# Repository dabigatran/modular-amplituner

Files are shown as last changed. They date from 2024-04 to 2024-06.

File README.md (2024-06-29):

# Modular Amplituner

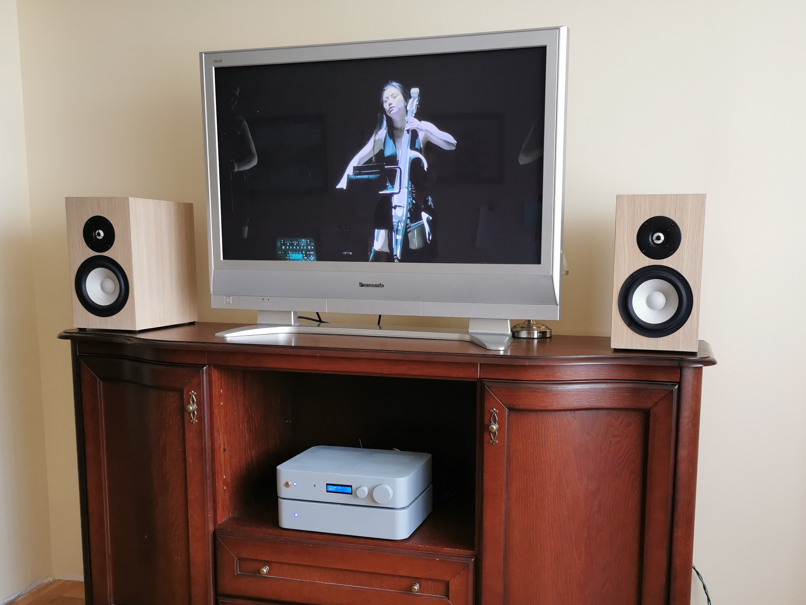
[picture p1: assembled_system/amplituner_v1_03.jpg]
Project Logo


## Overview

**Project Short Title:** Audio Path Control Using I2C and SPI Protocols</br>
**Project Full Title:** Audio path (I2S and analog bus) control using I2C and SPI protocols on the example of a modular audio-video system consisting of a receiver (tuner), an amplifier and a speaker system

**Abstract:** This project aims to create a modular audio/video system consisting of an audio/video receiver, audio amplifier, and stereo speaker system using commercially available components. The system uses universal I2C and SPI protocols for control and the I2S and analog bus for audio data transmission. Its modular design allows for both hardware and software upgrades, catering to advanced users and audio hobbyists.

**Introduction:**  The market for consumer devices for managing audio and video transmission is dominated by commercial solutions with a top-down imposed way of controlling and processing audio-visual data and no possibility of interference from the advanced user in the hardware part of the device as well as the software part. In addition, these systems are characterized by a lack of modularity, which consequently leaves the user without the possibility of a PC-like hardware upgrade. The goal of this project is to create a modular audio/video system consisting of an audio/video receiver, audio amplifier and stereo speaker system with software for home use, based on commercially available components. The system is planned to use universal I2C and SPI protocols to control individual modules and audio path (the I2S and analog bus). One of the system's most distinctive features is its modularity. This refers to the ability to make changes to the system, both in its individual components and in the software, according to the individual audio needs of the advanced user (audio hobbyist) over the course of the system's use.

## Features

### Speaker System
- **Sound Intensity:** 105dB (Max SPL)
- **Sensitivity:** 84dB
- **Frequency Range:** 45 – 24000 Hz
- **Impedance Range:** 4-8 Ohms

### Audio Amplifier
- **Power Rating:** Up to 150W
- **Type:** Class D stereo amplifier
- **Inputs:** 2x RCA audio inputs
- **Outputs:** 2x speaker outputs

### Audio Receiver
- **Digital Audio Sources:** Spdif, Bluetooth, USBC
- **Analog Audio Sources:** 2x RCA
- **Audio-Video Sources:** 4x HDMI
- **Outputs:** HDMI, 2x RCA
- **Control:** Volume, sound source, bass, treble, balance
- **Display:** LCD for current status and volume
- **Remote Control:** Infrared with Chromecast integration

## Assembled System - [presentations and photos](assembled_system/readme.md)

## System Architecture

### Schematics

#### Receiver - [technical specification](receiver/readme.md)
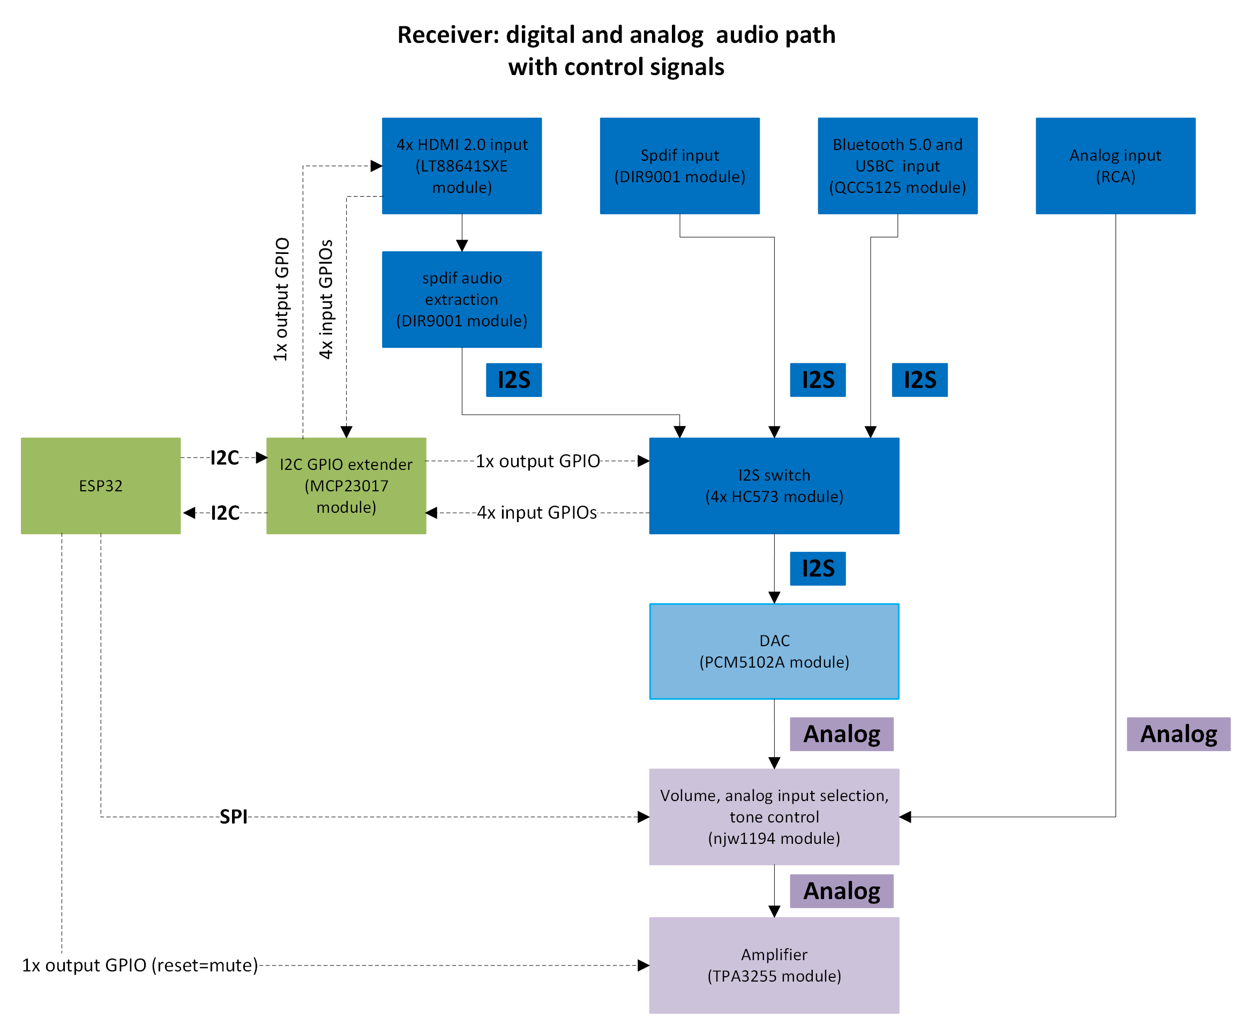
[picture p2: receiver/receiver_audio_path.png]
Receiver Audio Path Schematic


#### Amplifier - [technical specification](amplifier/readme.md)
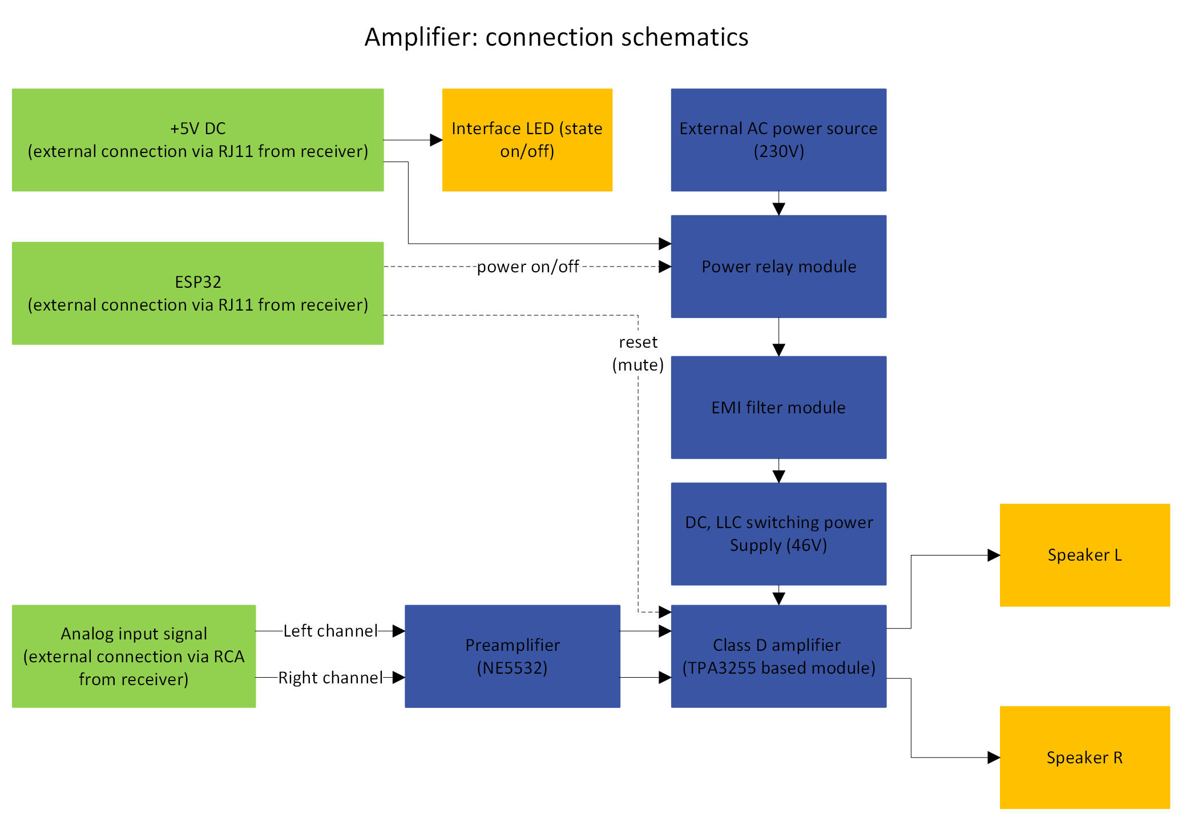
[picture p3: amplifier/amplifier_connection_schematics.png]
Amplifier Schematic


#### Speakers - [technical specification](speakers/readme.md) - based on Open Source [Bromo Project](https://sbacoustics.com/product/bromo/)
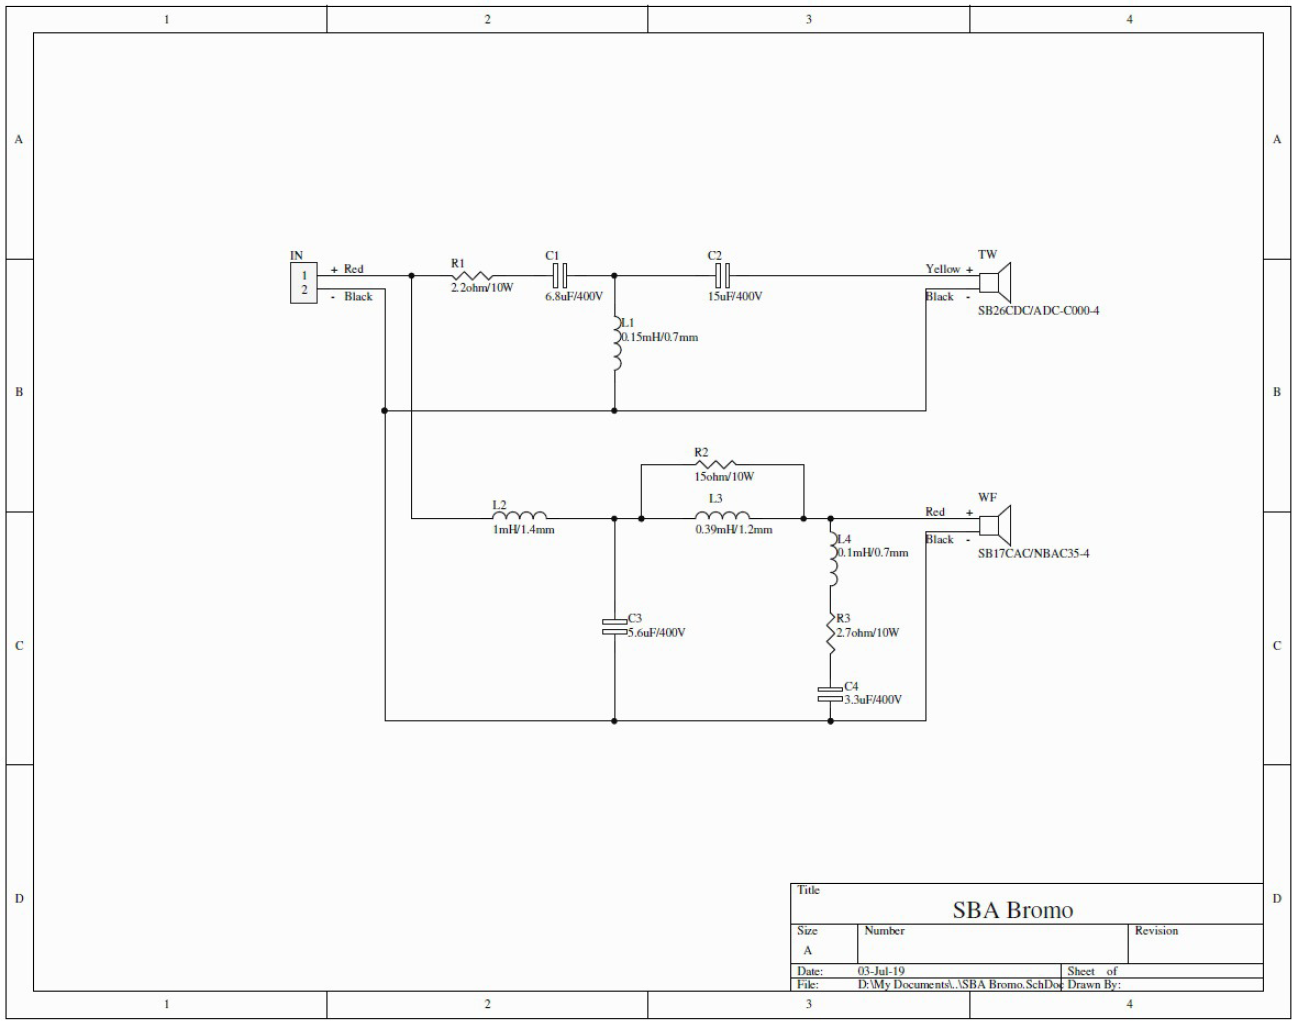
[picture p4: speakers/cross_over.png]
Speaker Cross-over Schematic

   
#### Firmware - [description and code](main/readme.md)
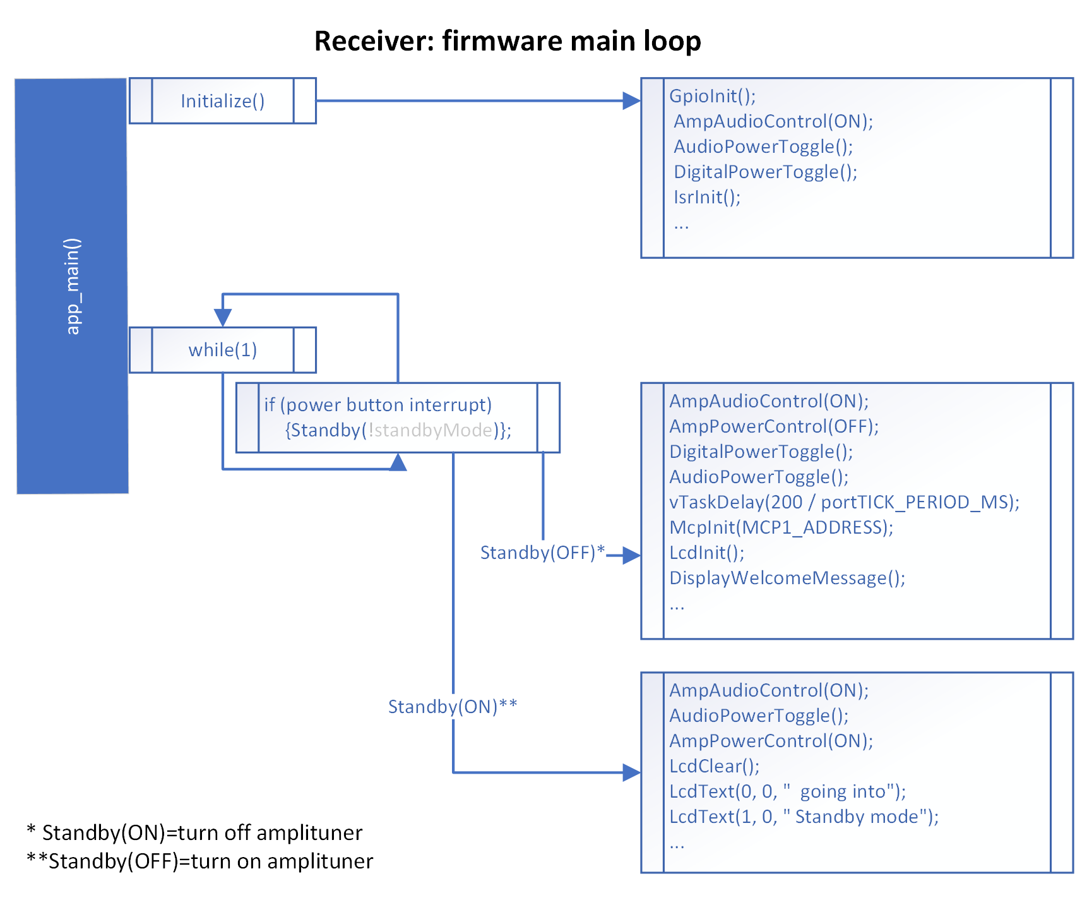
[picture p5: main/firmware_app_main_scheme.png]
Firmaware Main loop Schematic


## Installation

1. Clone the repository:
   ```bash
   git clone https://github.com/dabigatran/modular-amplituner.git

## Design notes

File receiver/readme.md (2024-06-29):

# Receiver Schematics

Receiver Audio Path Schematic

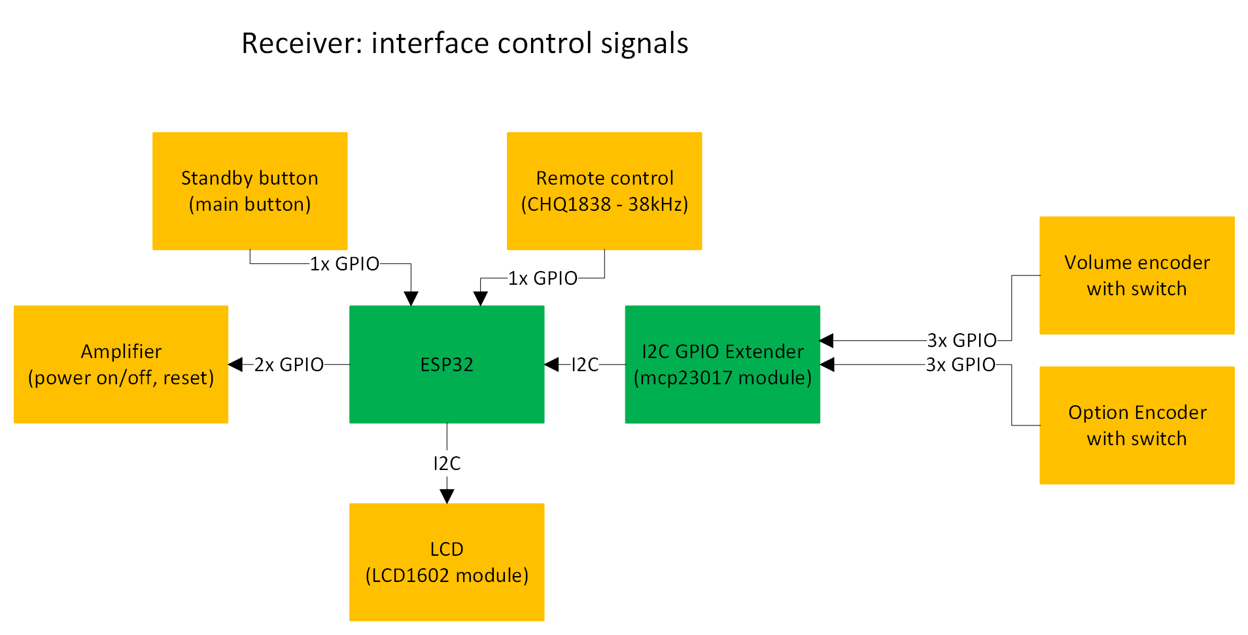
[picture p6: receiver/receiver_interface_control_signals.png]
Receiver User Interface Schematic


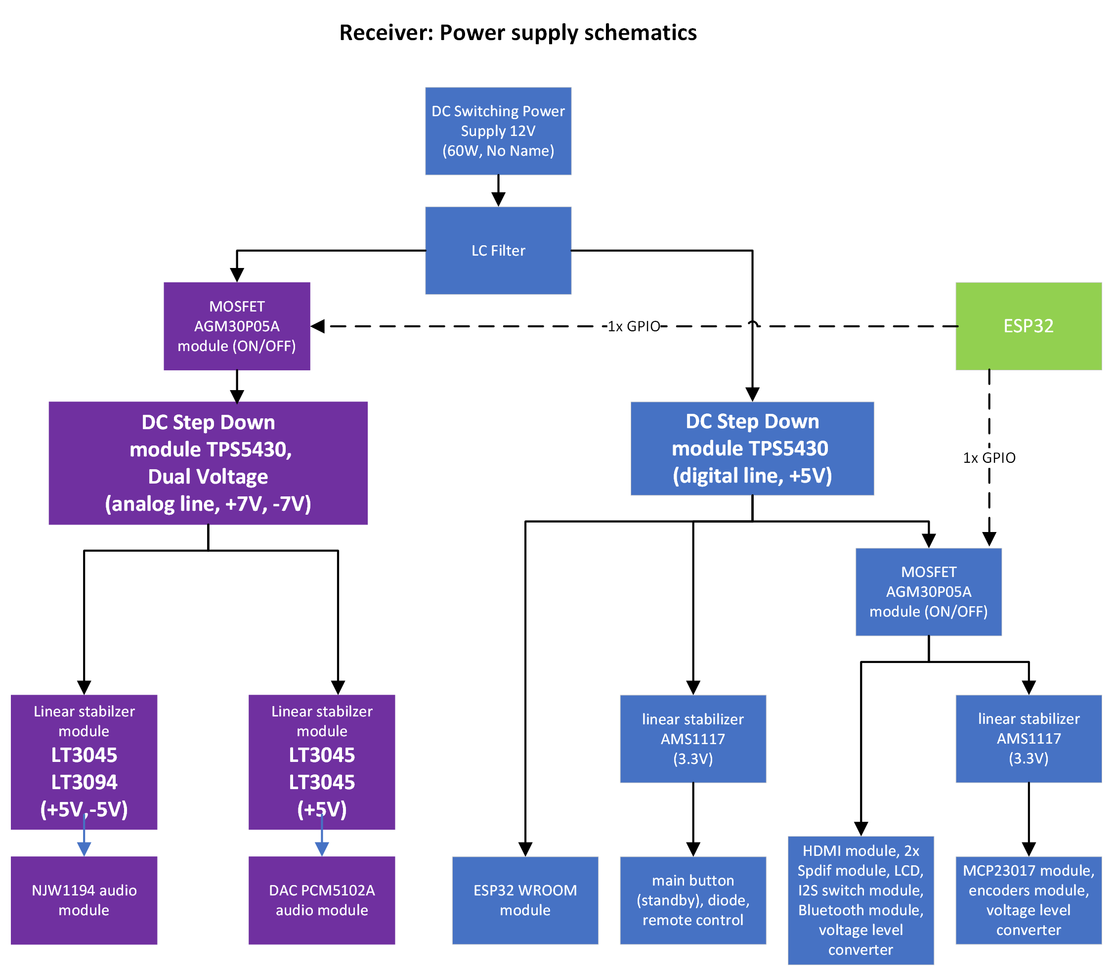
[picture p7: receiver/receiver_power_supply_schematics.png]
Receiver Power Supply Schematic


# Assembled Receiver

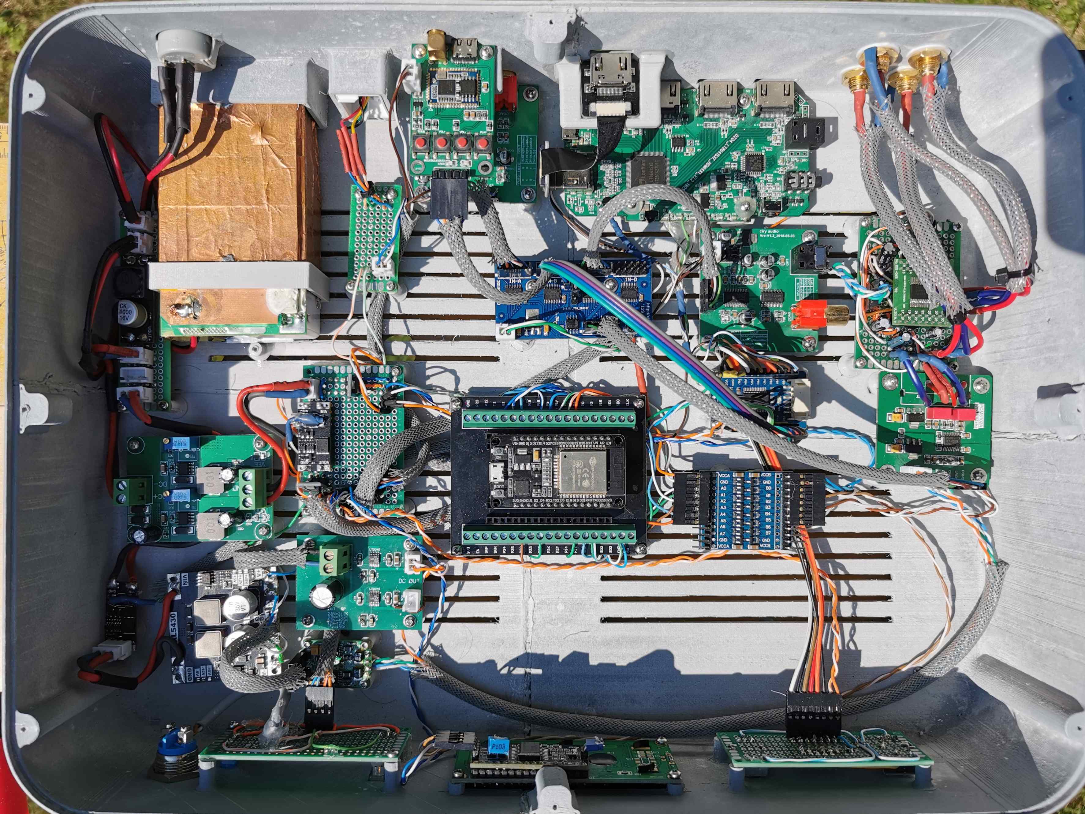
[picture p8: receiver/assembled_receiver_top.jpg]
Assembled Receiver Top


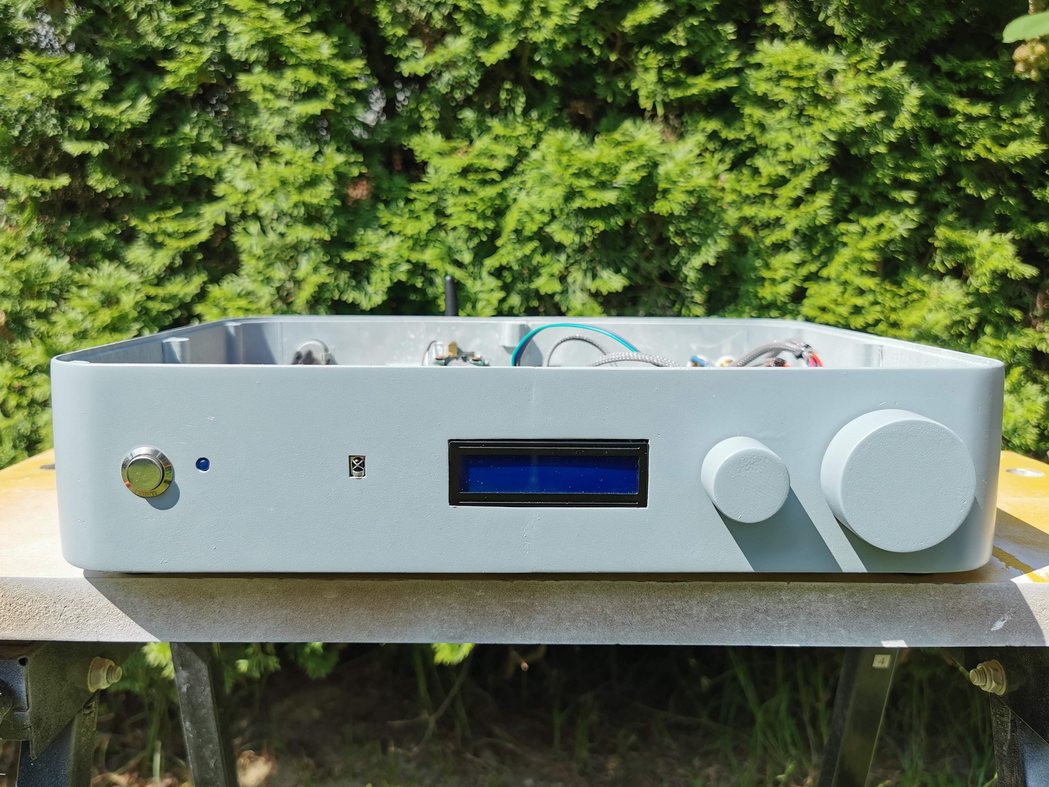
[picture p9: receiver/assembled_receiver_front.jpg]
Assemebled Receiver Front


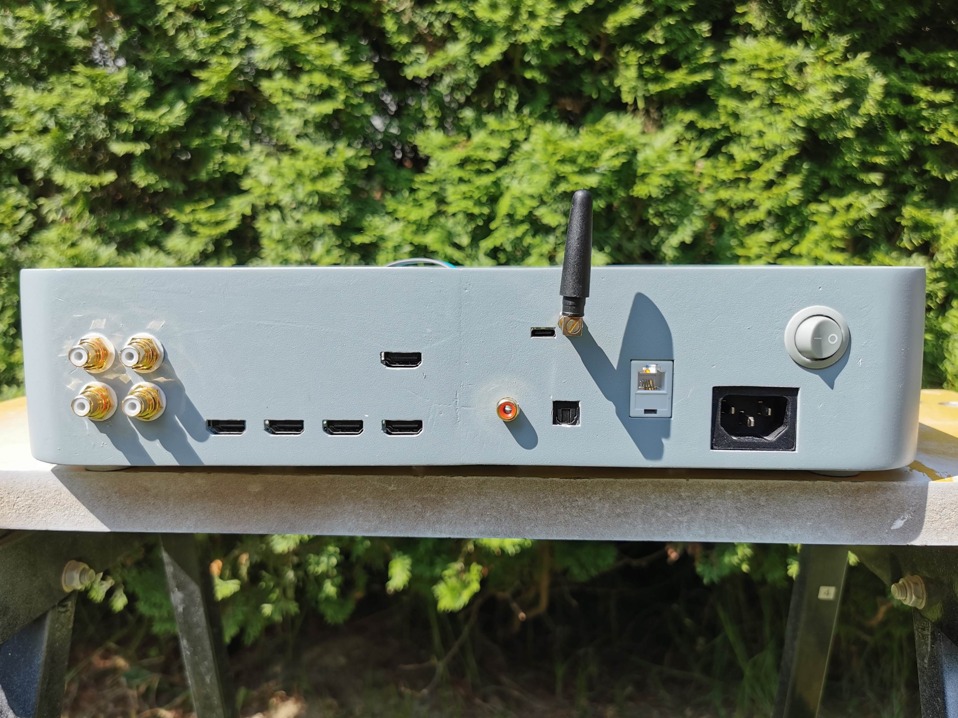
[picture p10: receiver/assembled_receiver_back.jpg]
Assemebled Receiver Back


# Receiver Components

### Power Supply
- **Switching Power Supply (60W, 12V)**
  - No-Name, taken from notebook
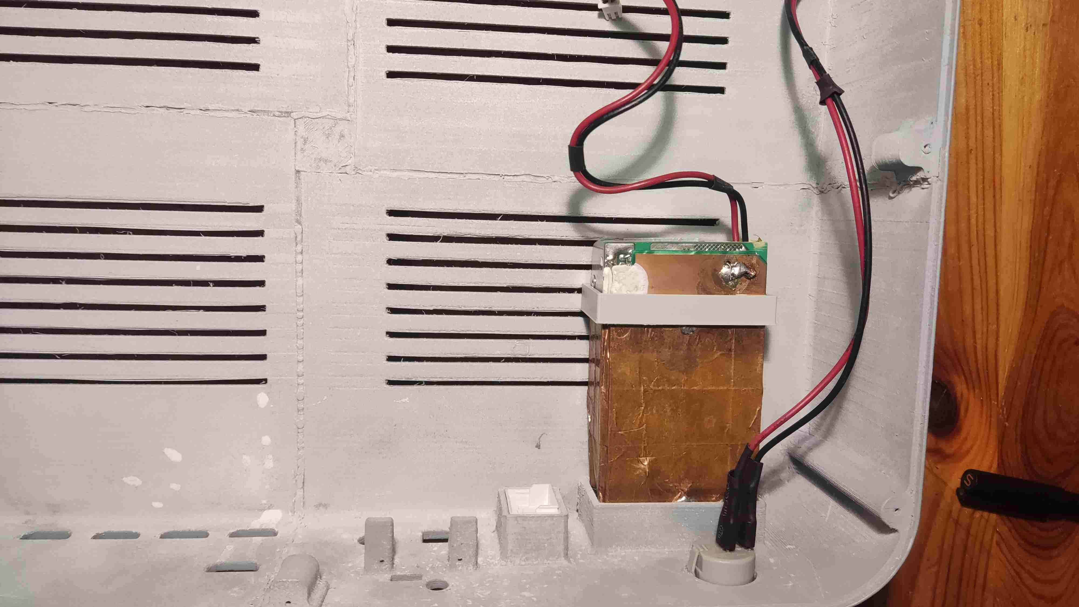
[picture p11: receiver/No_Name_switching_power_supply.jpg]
  - 

### Converters & Stabilizers
- **Step-Down Converter Modules (2x)**
  - No-Name, based on TPS5430 chip (Texas Instruments)
  - [Datasheet](../receiver/tps5430.pdf)
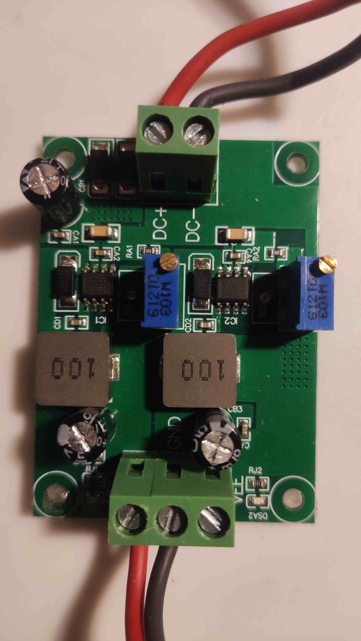
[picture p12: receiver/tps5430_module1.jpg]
  - 
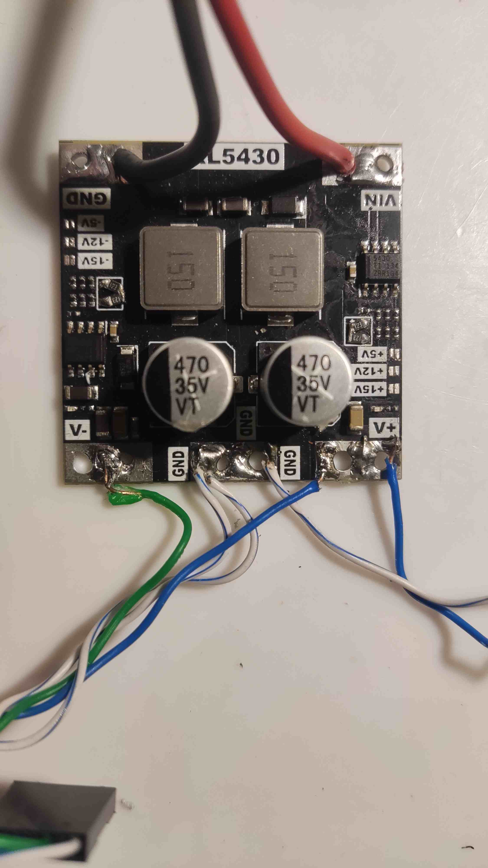
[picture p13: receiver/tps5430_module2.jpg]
  - 
- **Low-Noise Linear Stabilizer Module (+5V, 500mA)**
  - No-Name, based on 2x LT3045 chip (Analog Devices)
  - [Datasheet](../receiver/lt3045.pdf)
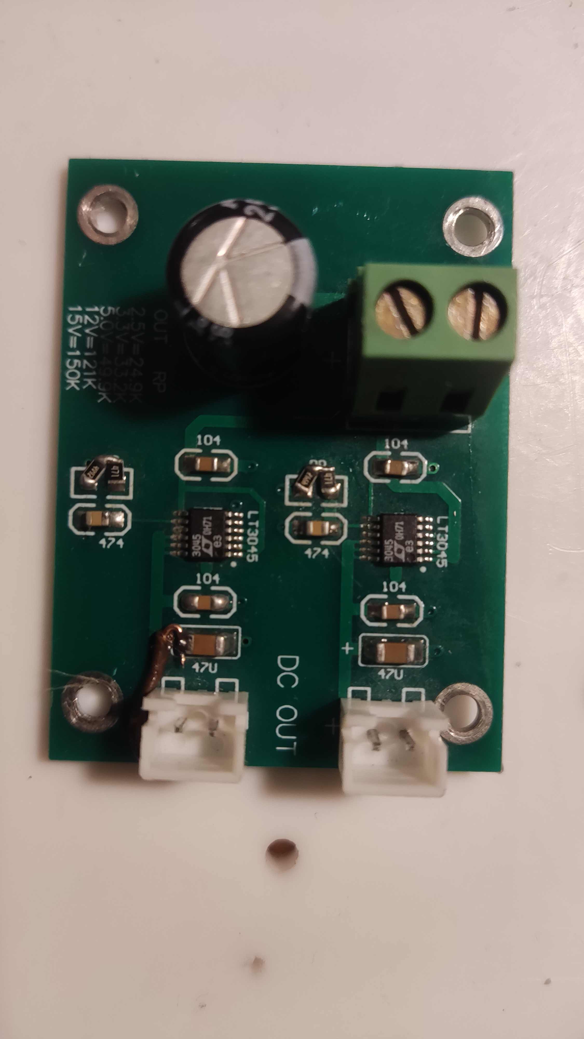
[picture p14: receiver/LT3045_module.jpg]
  - 
- **Low-Noise Linear Stabilizer Module (+5V and -5V, 300mA)**
  - FUTECH, based on LT3045 and LT3094 chips (Analog Devices)
  - [Datasheet](../receiver/LT3094.pdf)
  - [Datasheet](../receiver/lt3045.pdf)
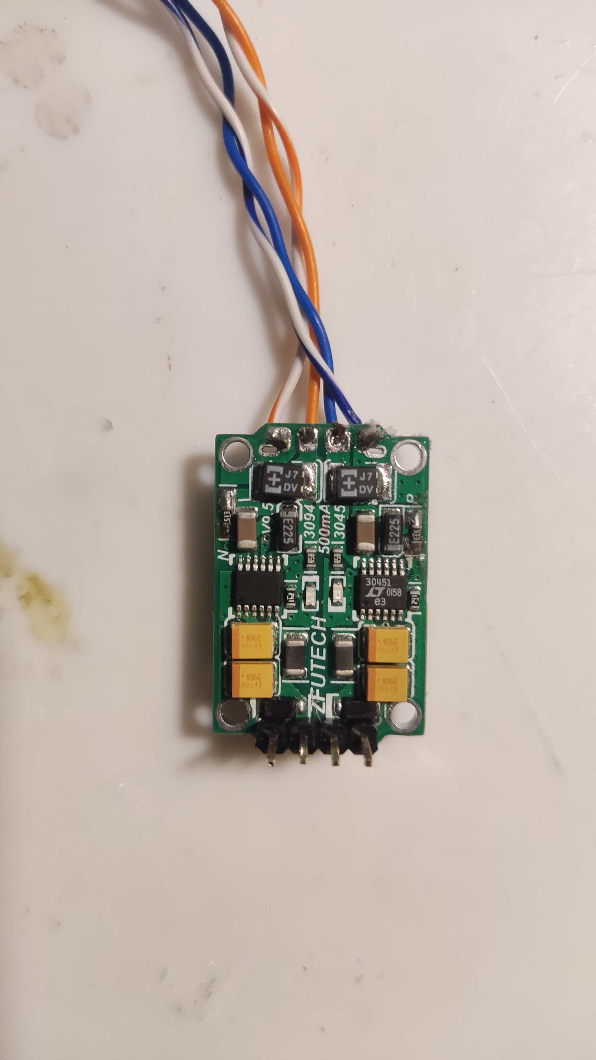
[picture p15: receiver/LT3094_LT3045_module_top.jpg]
  - 
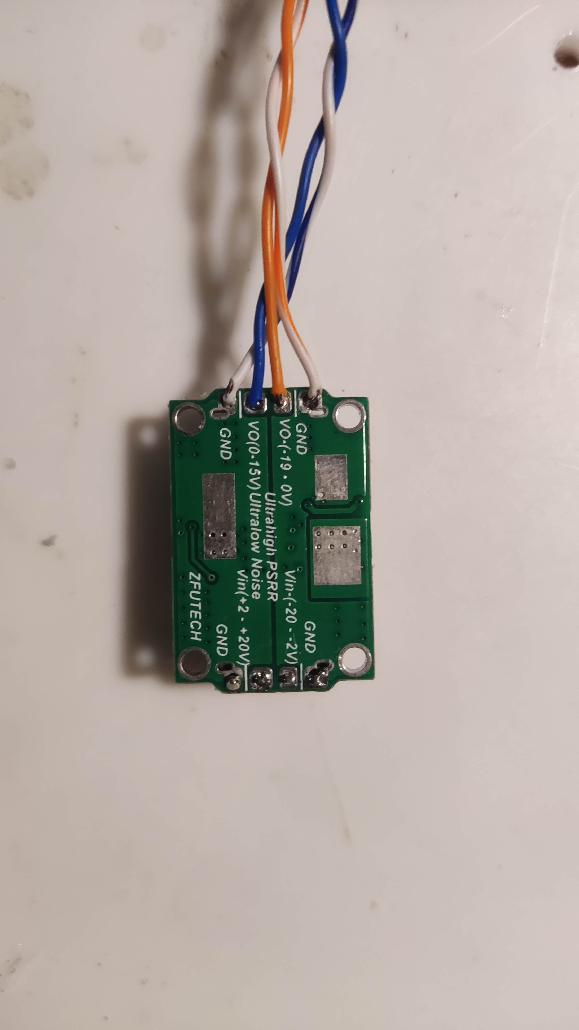
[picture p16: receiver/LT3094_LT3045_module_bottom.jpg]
  - 

### Microcontroller & Extenders
- **Microcontroller Module**
  - ESP32 WROOM-32 DEV KIT – Dual Core Tensilica LX6 240 MHz (Espressif Systems)
  - [Datasheet](../receiver/ESP-WROOM-32_datasheet.pdf)
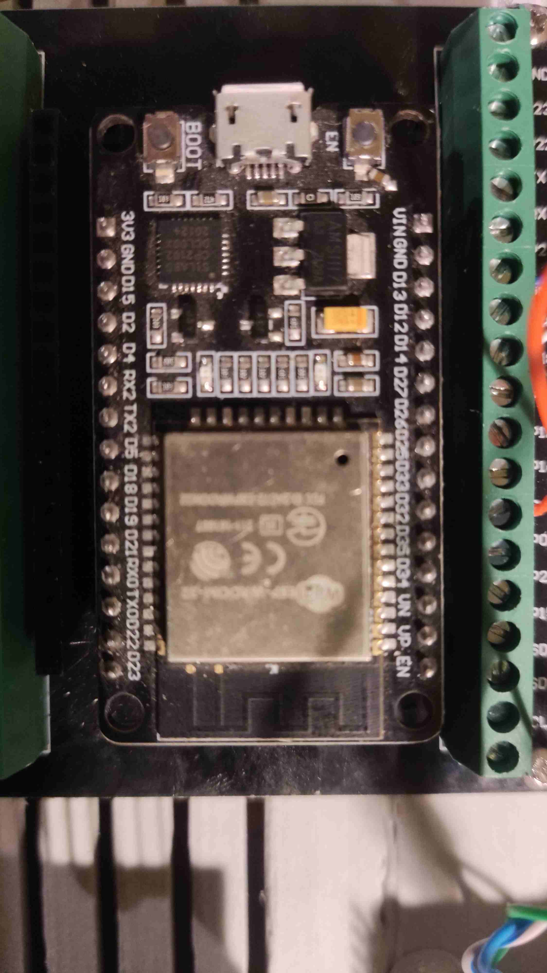
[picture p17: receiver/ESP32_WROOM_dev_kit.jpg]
  - 
- **I2C Bus Extender Module**
  - MCP23017 (Waveshare 15391)
  - [Datasheet](../receiver/MCP23017.pdf)
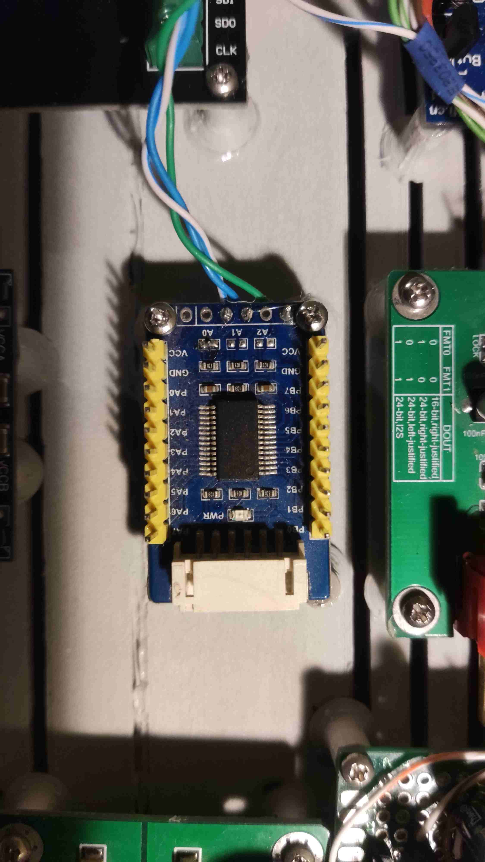
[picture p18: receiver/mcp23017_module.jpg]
  - 

### Displays & Controllers
- **LCD Display Module**
  - LCD1602 (No-Name)
  - [Datasheet](../receiver/LCD1602.pdf)
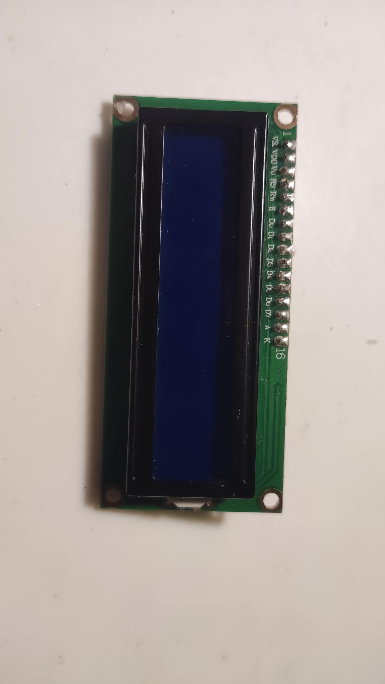
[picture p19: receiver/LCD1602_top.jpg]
  - 
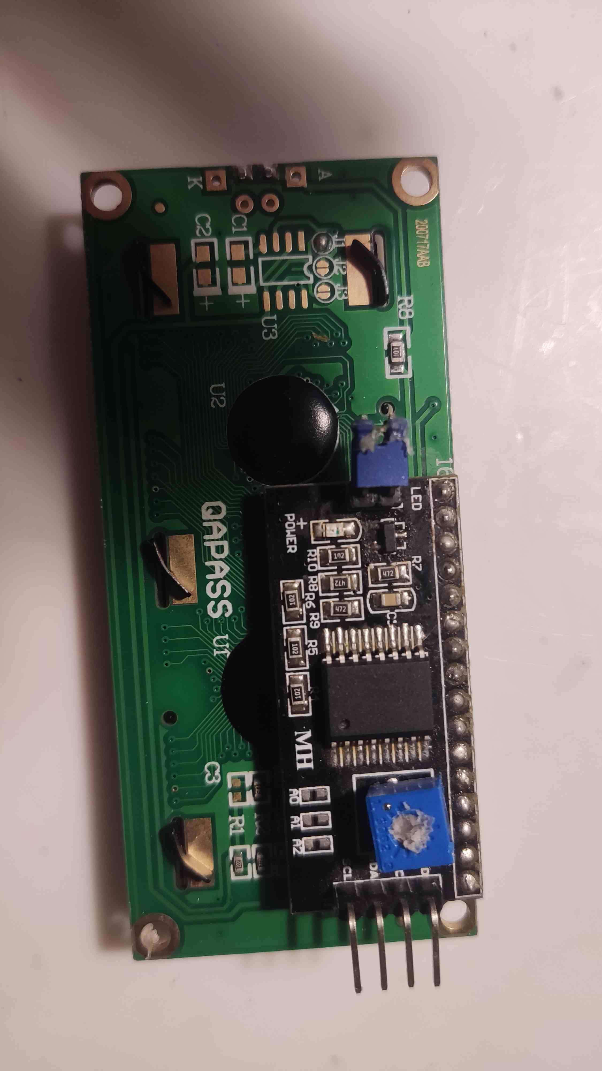
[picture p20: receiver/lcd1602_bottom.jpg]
  - 
- **LCD Controller Module (via I2C)**
  - Based on PCF8574 (Philips Semiconductors)
  - [Datasheet](../receiver/pcf8574.pdf)

### Audio Components
- **DAC Module**
  - Based on PCM5102 chip (Burr-Brown)
  - [Datasheet](../receiver/pcm5102a.pdf)
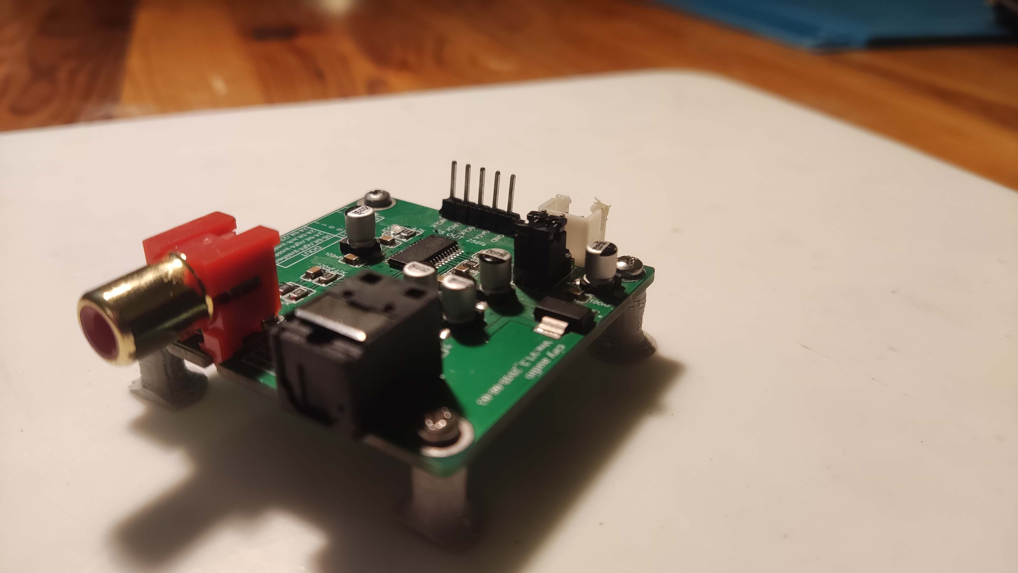
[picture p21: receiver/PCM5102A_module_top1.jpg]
  - 
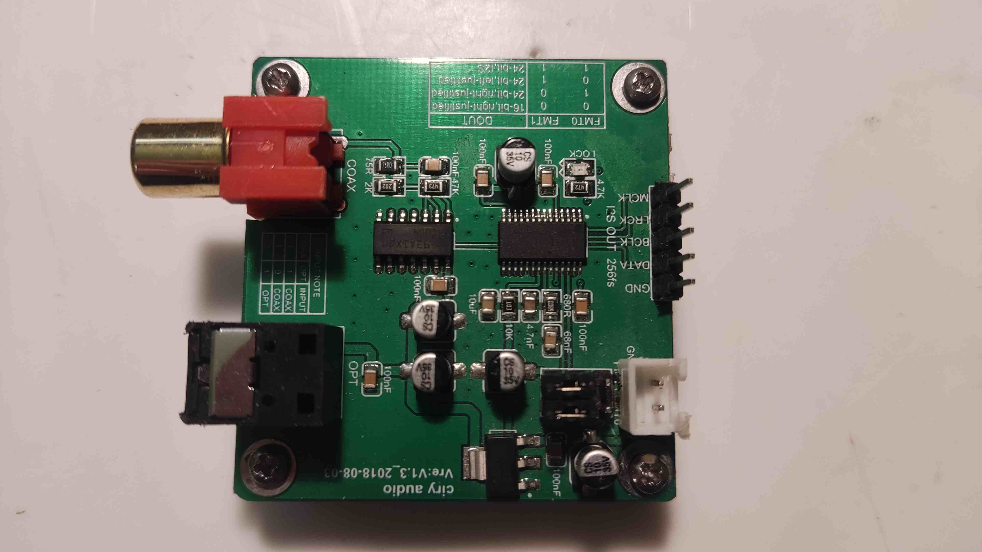
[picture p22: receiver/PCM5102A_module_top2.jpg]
  - 
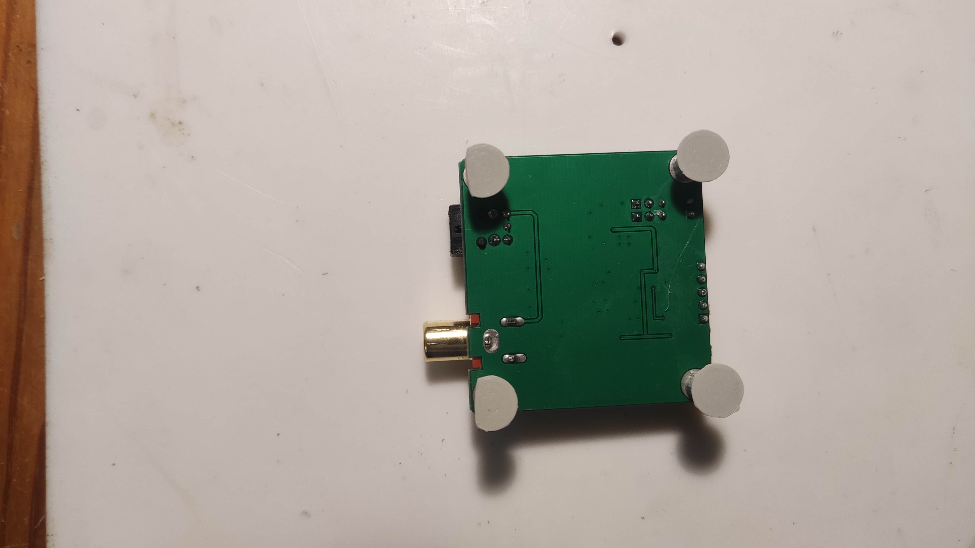
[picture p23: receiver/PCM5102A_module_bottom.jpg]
  - 
- **Analog Audio Control Module**
  - Based on NJW1194 chip (New Japan Radio)
  - [Datasheet](../receiver/NJW1194.PDF)
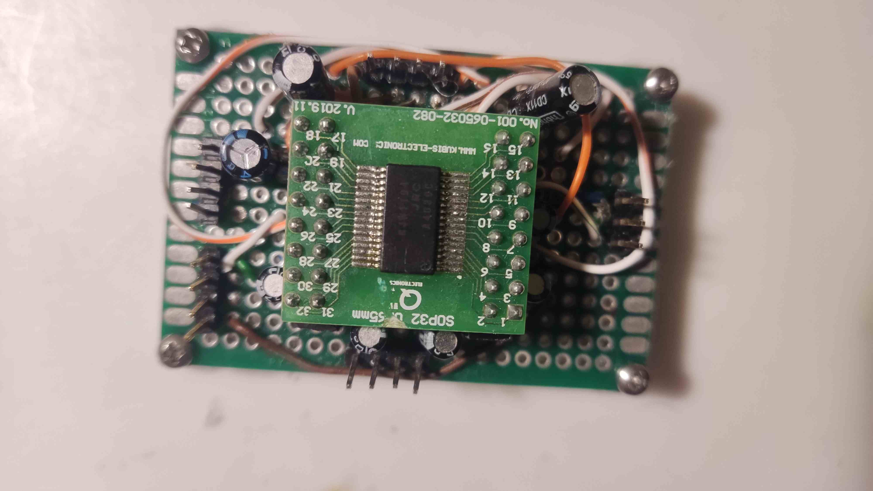
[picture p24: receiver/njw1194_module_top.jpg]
  - 
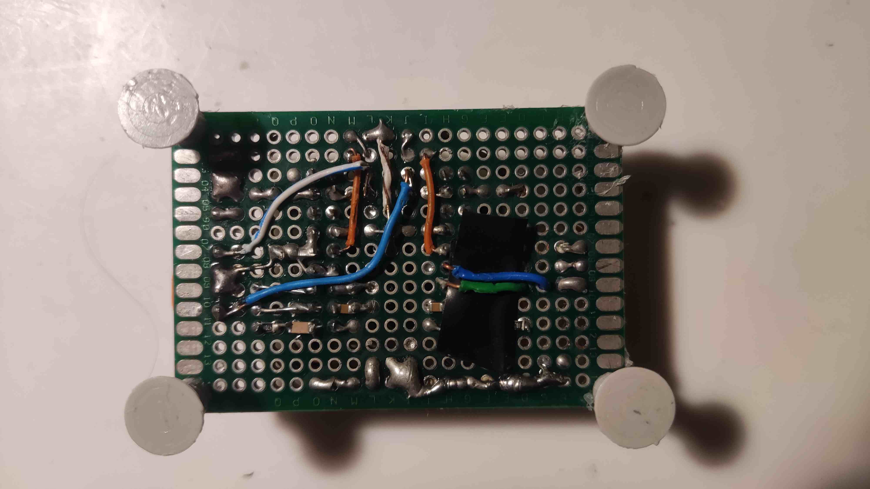
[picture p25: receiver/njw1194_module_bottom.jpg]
  - 
- **Bluetooth 5.0 Stereo Module**
  - Based on QCC5125 chip (Qualcomm)
  - [Datasheet](../receiver/SJR-BTM525_SPEC.pdf)
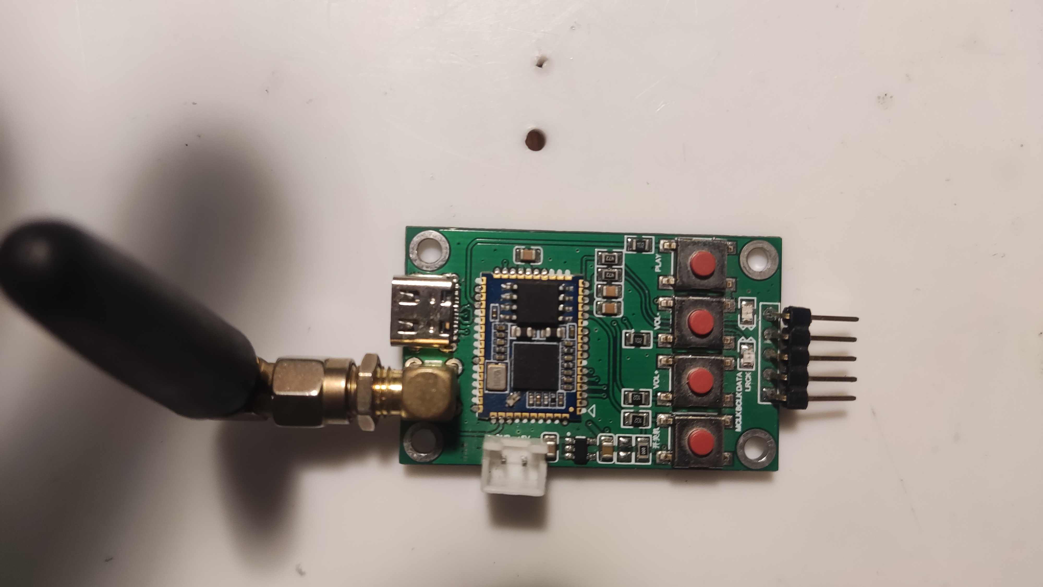
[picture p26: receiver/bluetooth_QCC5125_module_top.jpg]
  - 
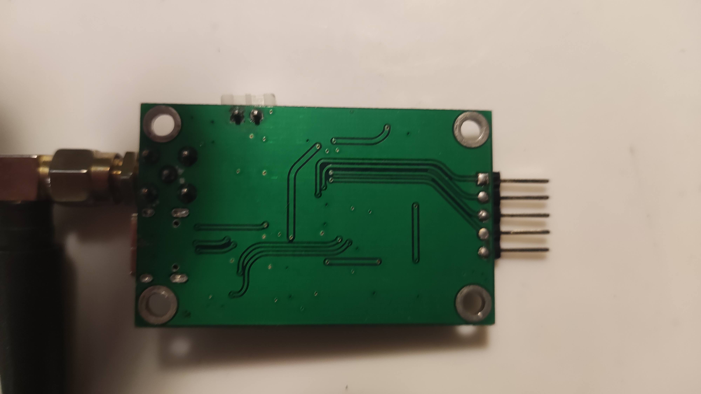
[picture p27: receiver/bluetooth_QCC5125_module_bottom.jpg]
  - 
- **Digital Signal Converter (SPDIF to I2S)**
  - Based on DIR9001 chip (Texas Instruments)
  - [Datasheet](../receiver/dir9001.pdf)
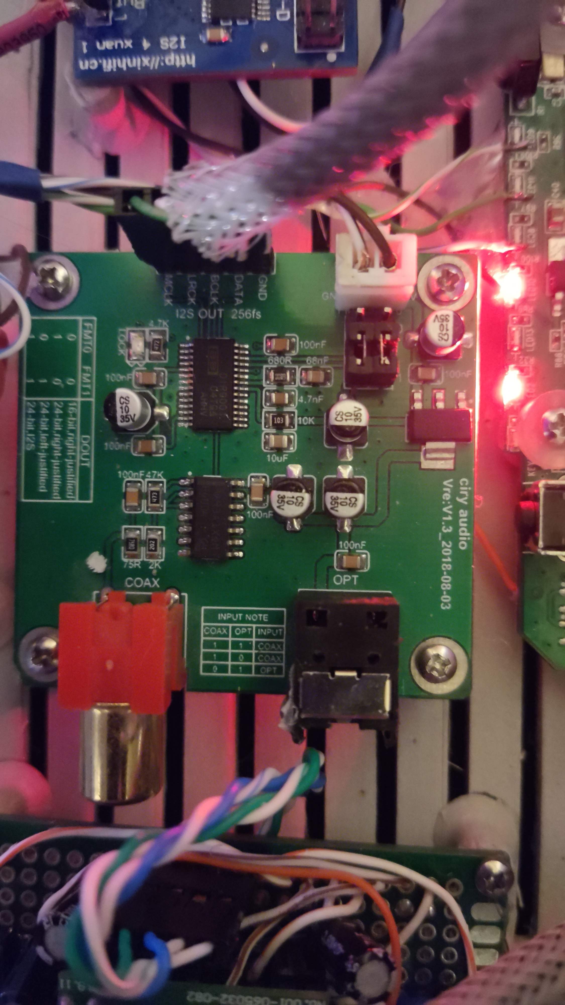
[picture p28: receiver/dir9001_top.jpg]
  - 
- **I2S Signal Switch Module**
  - Based on HC273 chip (Texas Instruments)
  - [Datasheet](../receiver/cd54hc573.pdf)
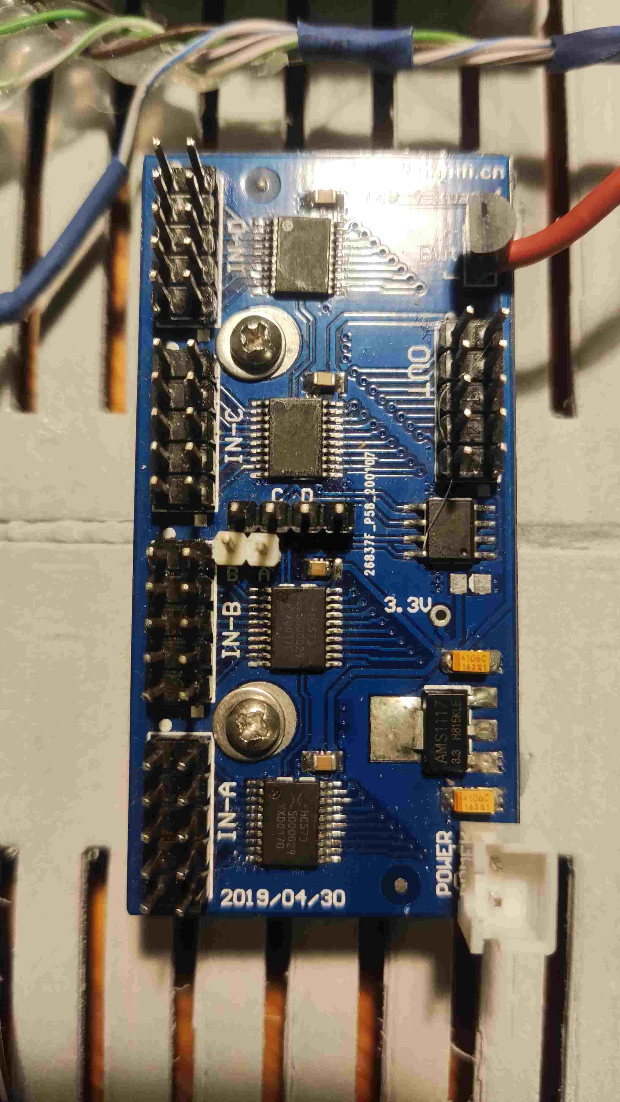
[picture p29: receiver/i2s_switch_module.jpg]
  - 
  - 

### HDMI & Logic Converters
- **HDMI Source and Output Control Module**
  - No-Name, based on LT8641SXE chip (Lontium Semiconductors)
  - [Datasheet](../receiver/LT8641SXE_Product_Brief.pdf)
  - 
  - 
  - 
  - 
- **5V-3.3V Logic Level Converter Module**
  - No-Name
  - 

### Controls & Interfaces
- **Control Module with Encoders**
  - Two PEC11H series encoders and switch (Bourns)
  - [Datasheet](../receiver/pec11h-1879218.pdf)
  - 
  - 
- **Inverter Module with Schmitt Circuit**
  - Based on 74HC14 integrated circuit (Diodes Incorporated)
  - [Datasheet](../receiver/74HC14.pdf)

### Miscellaneous
- **Other Components**
  - NPN transistors, resistors, capacitors, universal PCBs, wiring, RCA connectors, USB, Bluetooth antennas, heat sink
- **Enclosure**
  - See [Enclosure](../enclosure/readme.md)

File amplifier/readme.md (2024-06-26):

# Amplifier Schematics

Amplifier Schematic
Assembled amplifier photo
Assembled amplifier photo
Assembled amplifier photo
Assembled amplifier photo
Assembled amplifier photo

# Amplifier Components

## Power Supply
- **Dual LLC 500W, 46V Switching Power Supply Module**
  - Lusya C1-009
  - LLC Power Supply photo
  - LLC Power Supply photo
  - LLC Power Supply photo

## Amplifier Modules
- **260W Class D Stereo Amplifier Module**
  - 3eaudio model EAUMT-0260-2-B, based on TPA3255 IC (Texas Instruments)
  - THD+N < 0.01% in the range of 0.3W - 200W at 4Ω, 111dBA dynamic range
  - [3eaudio Product Page](https://www.3e-audio.com/amplifier-kits/tpa3255-2ch-260w/)
  - [Product Datasheet](../amplifier/DS_EAUMT-0260-2-A_Rev1.0.pdf)
  - [tpa3255 Datasheet](../amplifier/tpa3255B.pdf)
  - DC Voltage supplied - 46V (compromise between Power, THD+N, Heat, speakers resistance)
  - output power rating - 150W (page 11, Figure 8, [tpa3255 Datasheet](../amplifier/tpa3255B.pdf)) .
  - Class D Amplifier photo
  - Class D Amplifier photo

## EMI & Safety
- **EMI Filter Module**
  - No-Name
  - EMI Filter Photo
  - EMI Filter Photo
- **Power Relay**
  - No-Name
  - Power Relay Photo
  - Power Relay Photo

## Enclosure
- **Enclosure**
  - See [Enclosure](../enclosure/readme.md)

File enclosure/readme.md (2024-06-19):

# Enclosure

## STLs
- [Amplifier Base](../enclosure/amplifier_base.stl)
- [Receiver Base](../enclosure/receiver_base.stl)
- [Receiver and Amplifier Cover](../enclosure/receiver_and_amplifier_cover.stl)
- [Receiver and Amplifier Cover Support](../enclosure/receiver_and_amplifier_cover_support.stl)
- [Receiver and Amplifier PCB Support](../enclosure/receiver_and_amplifier_pcb_support.stl)
- [Receiver and Amplifier Pad](../enclosure/receiver_and_amplifier_pad.stl)
- [Receiver Power Supply Support](../enclosure/receiver_power_supply_support.stl)
- [Volume Knob](../enclosure/volume_knob.stl)
- [Option Knob](../enclosure/option_knob.stl)

## Printing Details
- **Material**: Impact PLA (Fiberology)
- **Print Temperature**: 225°C
- **Print Bed Temperature**: 50°C for the first layer, 35°C for subsequent layers
- **Adhesive**: Dimafix
- **Print Layer Height**: 0.2 mm
- **Supports**: Yes (use according to your printer's requirements)

## Comments
- **Adhesives**: PCB supports and power supply pads were glued to the case with CA300 and activator.
- **Mounting**: PCBs, covers, and pads were screwed to the case.
- **Print Bed Constraints**: Due to the small print bed of my printer (220x220mm), I had to divide covers and the base of the amplifier and receiver into 4 parts. Printing took 120 hours for all components, and I used approximately 2kg of Impact PLA.
- **Printing Orientation**: Printed with the front face and back face of the receiver/amplifier on the printer's bed to hide print layers.
- **Post-Processing**: To hide layering, I additionally sanded the cases and used primer, car filler, and spray paint.

## Photos
Printer
Receiver Enclosure Front
Receiver Enclosure Front
Receiver Enclosure Front
Spray Glue Filler Primer

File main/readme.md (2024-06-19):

# Firmware
- app_main() Schematics

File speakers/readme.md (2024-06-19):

# Speakers 
- based on SBAcoustics Open Source [Bromo Project](https://sbacoustics.com/product/bromo/)

# Speaker Components

## Tweeters
- **2x SB26CDC-C000-4 Tweeter**
  - [Datasheet](../speakers/SB26CDC-C000-4.pdf)

## Mid-Bass Speakers
- **2x SB17CAC35-4 Mid-Bass Speaker**
  - [Datasheet](../speakers/6in-SB17CAC35-4.pdf)

## Crossovers
- **Set of Components for Two Crossovers (Jantzen Audio)**
  - [Crossover Schematic](../speakers/Bromo-Crossover-Schematic.pdf)

## Enclosure
- **18 mm Thick MDF Board**
  - [Cabinet Drawing](../speakers/Bromo-Cabinet-Drawing.pdf)

## Additional Components
- **Set of Connectors**
- **Bass-Reflex Tunnels**
- **Veneer and Veneer Glue**
- **Varnish**

## Photos
  
  
  
  
  
  
  
  
  



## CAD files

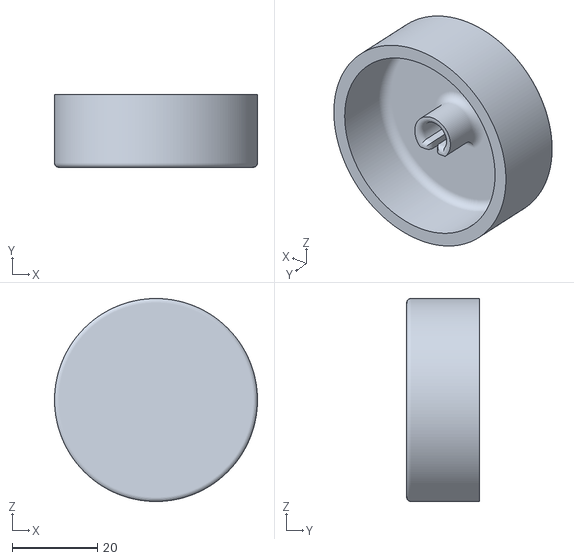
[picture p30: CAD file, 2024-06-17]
enclosure/volume_knob.stl
47.5 x 17.0 x 47.5

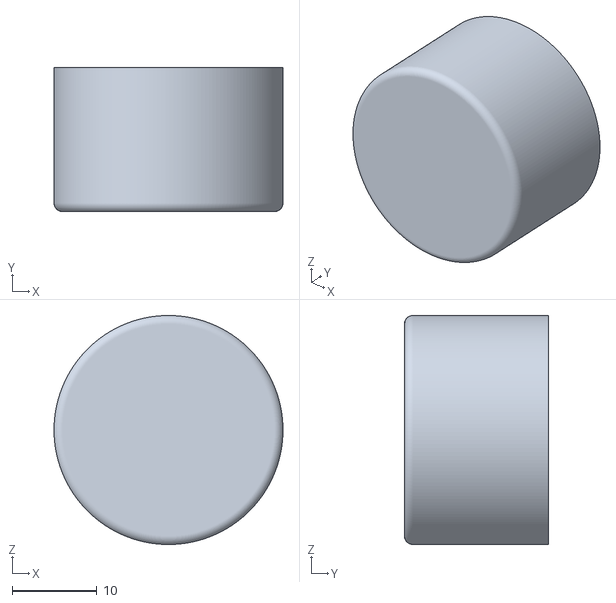
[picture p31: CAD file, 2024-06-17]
enclosure/option_knob.stl
27.0 x 17.0 x 27.0

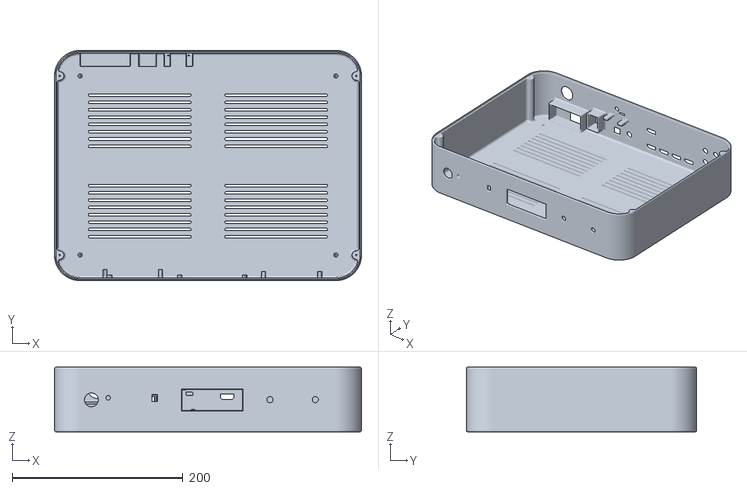
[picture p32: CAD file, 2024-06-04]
enclosure/receiver_base.stl
360.0 x 270.0 x 76.0

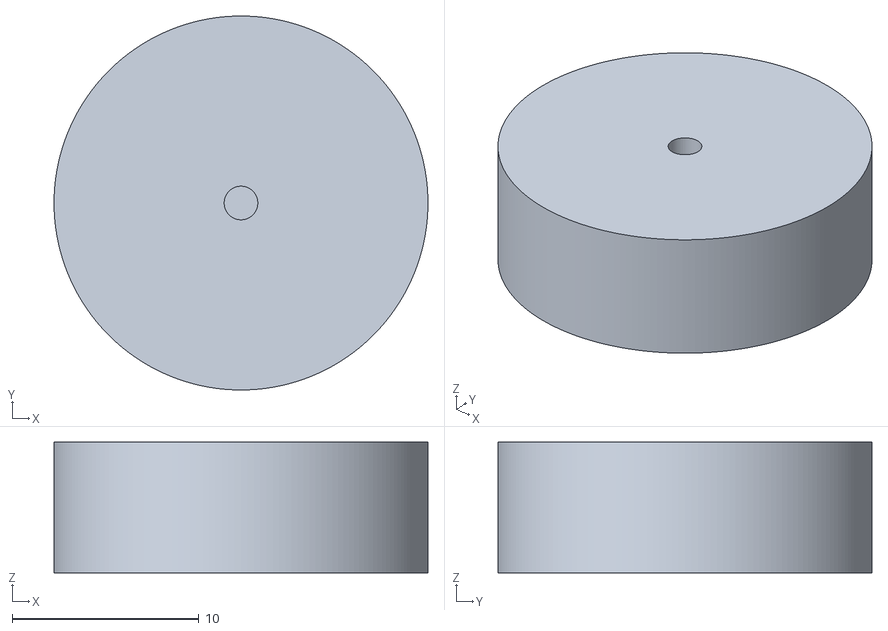
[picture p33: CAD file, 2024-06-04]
enclosure/receiver_and_amplifier_pad.stl
20.0 x 20.0 x 7.00

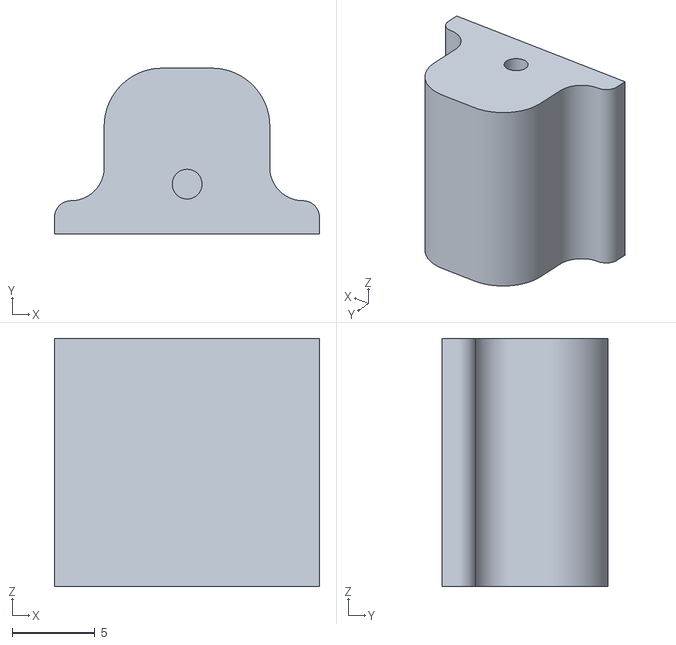
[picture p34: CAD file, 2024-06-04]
enclosure/receiver_and_amplifier_cover_support.stl
16.0 x 10.0 x 15.0

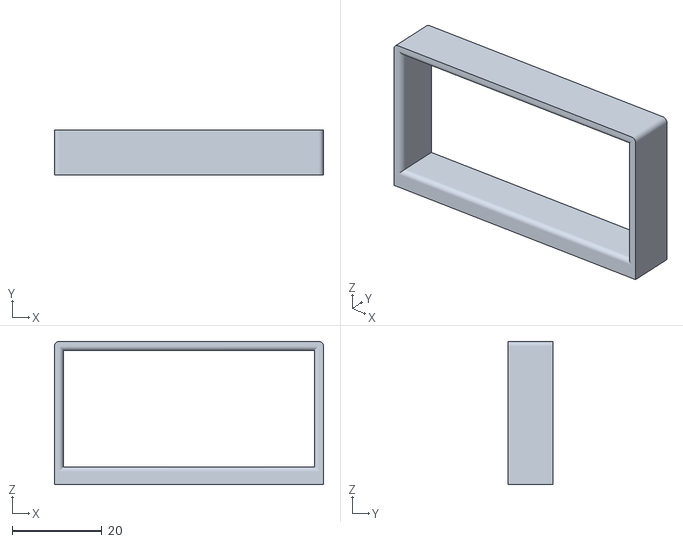
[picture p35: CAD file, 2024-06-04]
enclosure/receiver_power_supply_support.stl
60.0 x 10.0 x 31.9

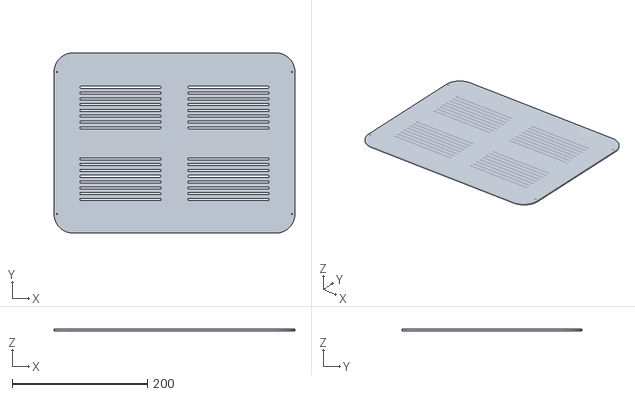
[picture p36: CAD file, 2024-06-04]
enclosure/receiver_and_amplifier_cover.stl
356.6 x 266.6 x 3.00

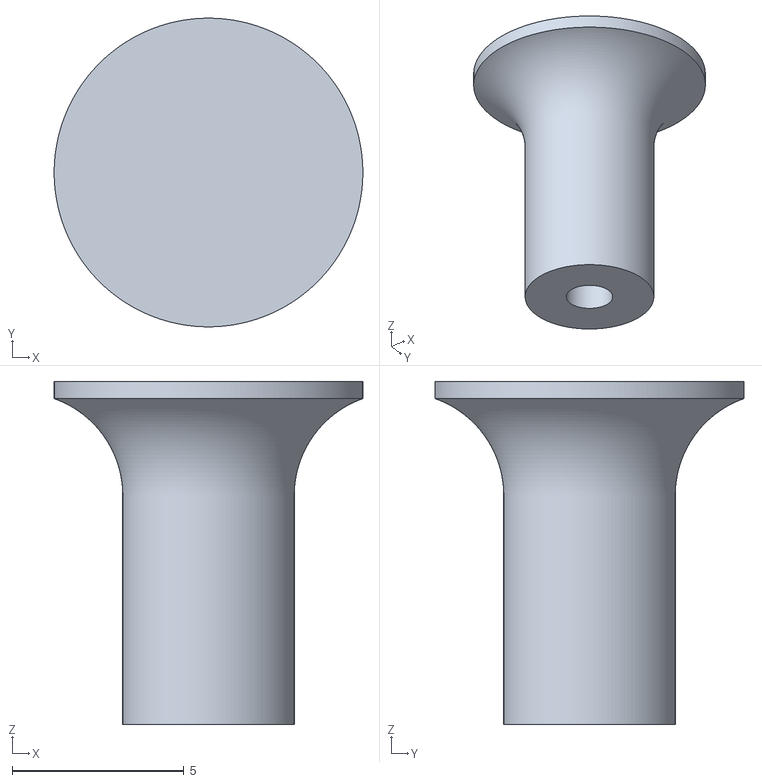
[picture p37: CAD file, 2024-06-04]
enclosure/receiver_and_amplifier_pcb_support.stl
9.00 x 9.00 x 10.0

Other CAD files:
enclosure/amplifier_base.stl

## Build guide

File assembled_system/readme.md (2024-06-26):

# Assembled and working system (receiver, amplifier, speakers)
## Presentations
[Amplituner User Interface (download .mp4 to view)](https://raw.githubusercontent.com/dabigatran/modular-amplituner/main/assembled_system/amplituner_v1_main.mp4)

[Amplituner Chromecast Remote Control (download .mp4 to view)](https://raw.githubusercontent.com/dabigatran/modular-amplituner/main/assembled_system/amplituner_v1_remote.mp4)

## Photos
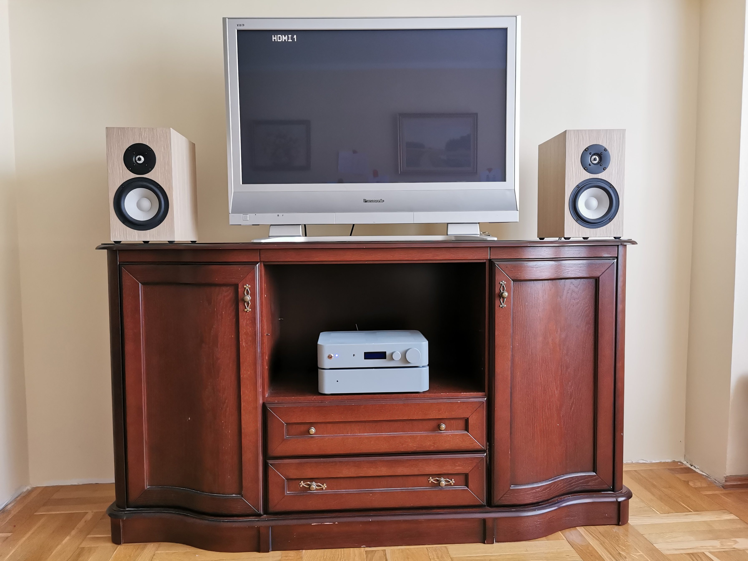
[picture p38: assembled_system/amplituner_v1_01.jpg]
amplituner_1

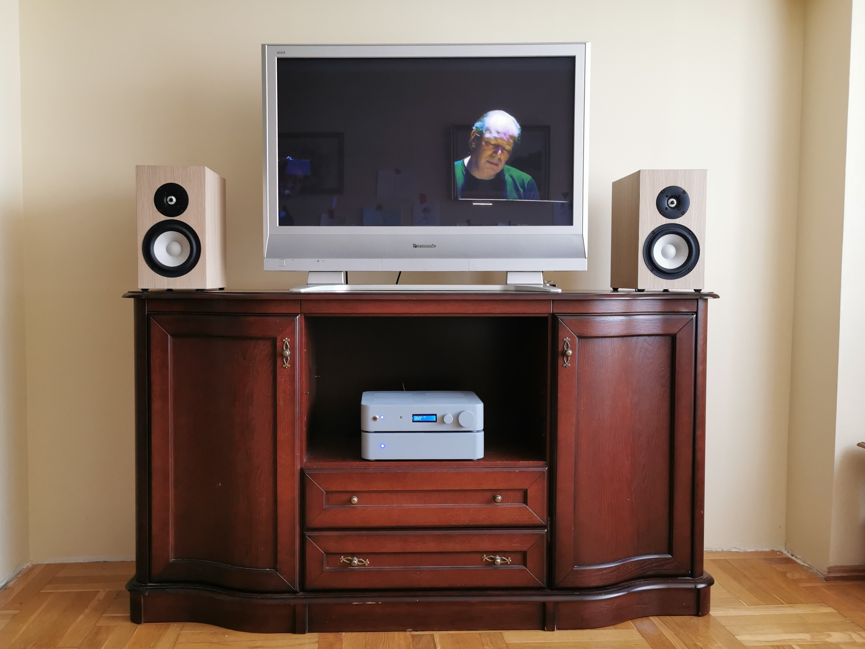
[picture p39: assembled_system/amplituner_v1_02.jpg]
amplituner_2

amplituner_3
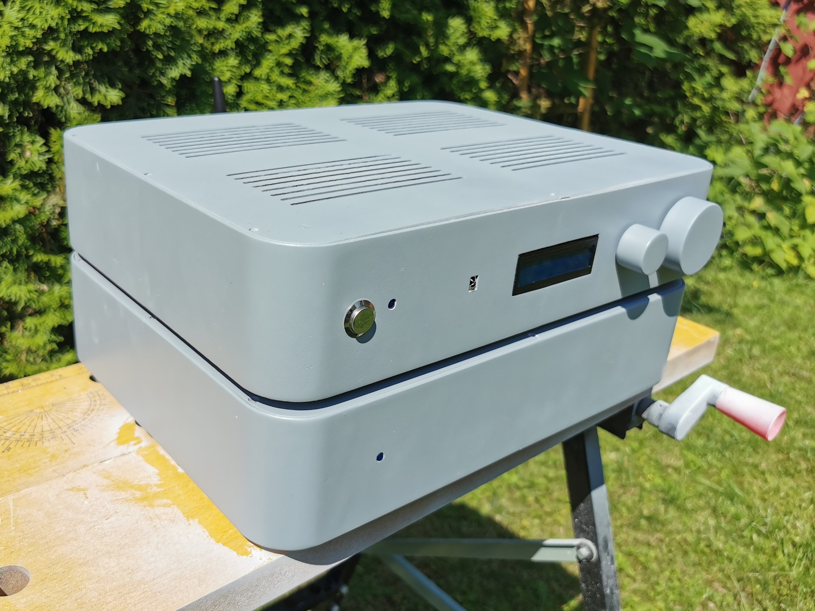
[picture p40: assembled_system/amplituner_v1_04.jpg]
amplituner_4

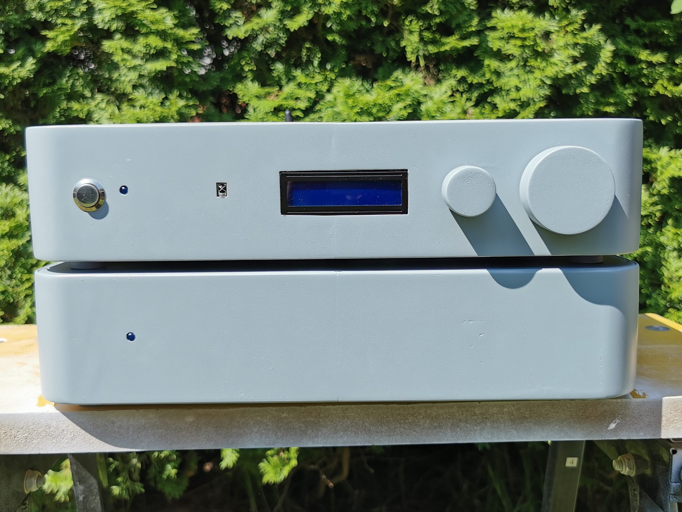
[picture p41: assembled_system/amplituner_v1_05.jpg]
amplituner_5

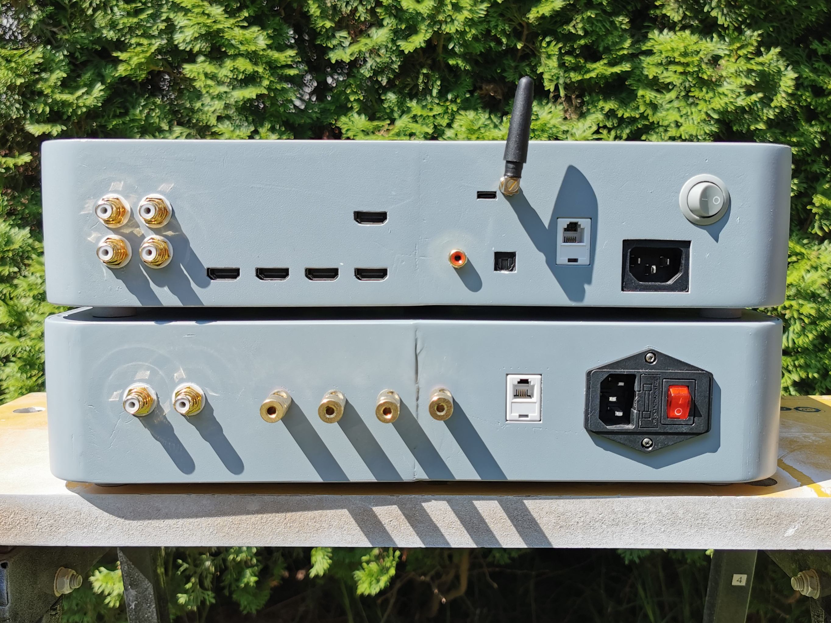
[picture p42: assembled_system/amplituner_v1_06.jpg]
amplituner_6

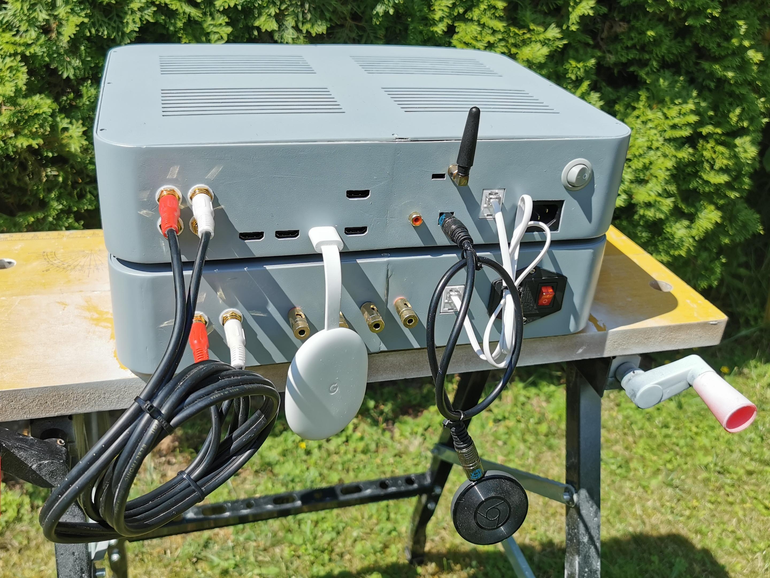
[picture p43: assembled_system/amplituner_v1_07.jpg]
amplituner_7

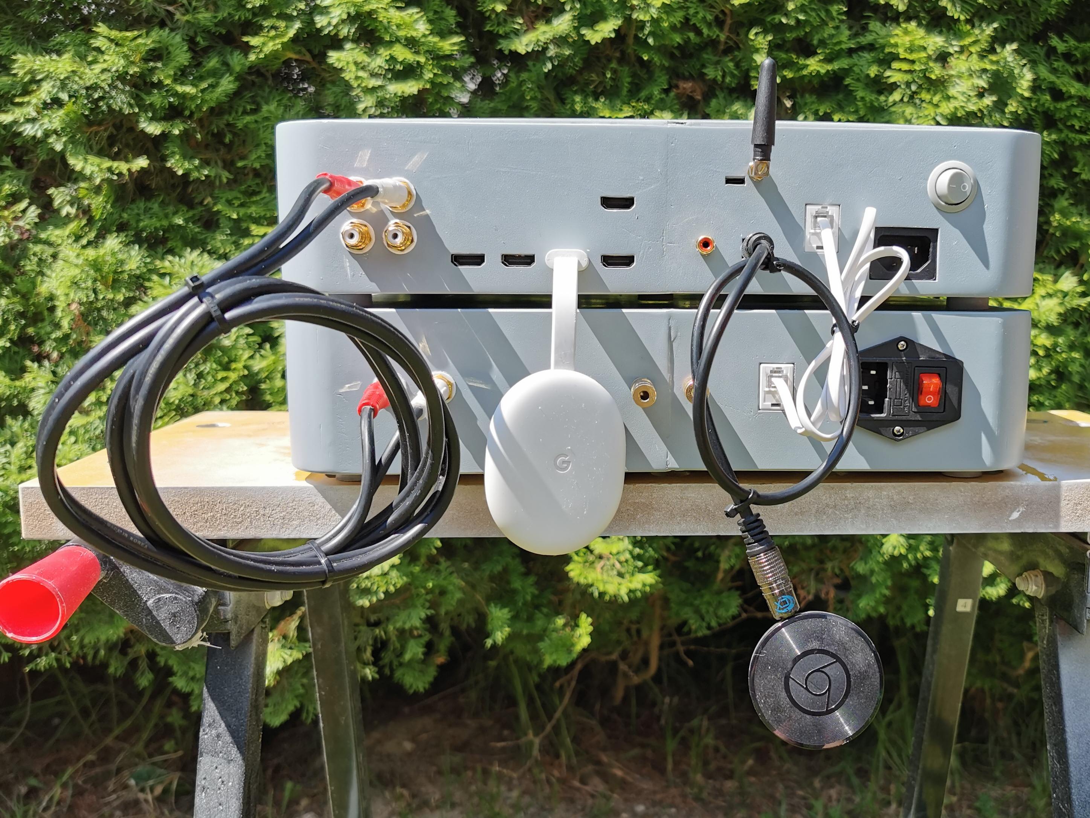
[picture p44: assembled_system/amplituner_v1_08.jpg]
amplituner_8

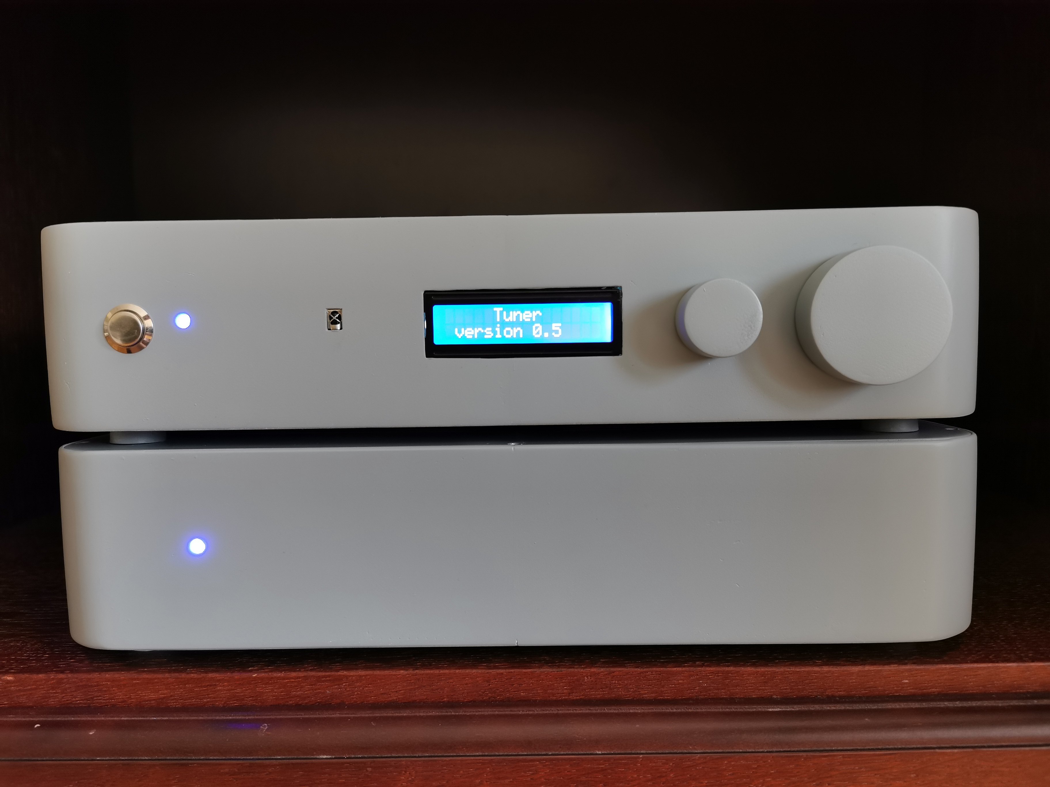
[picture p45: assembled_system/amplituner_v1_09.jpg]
amplituner_9

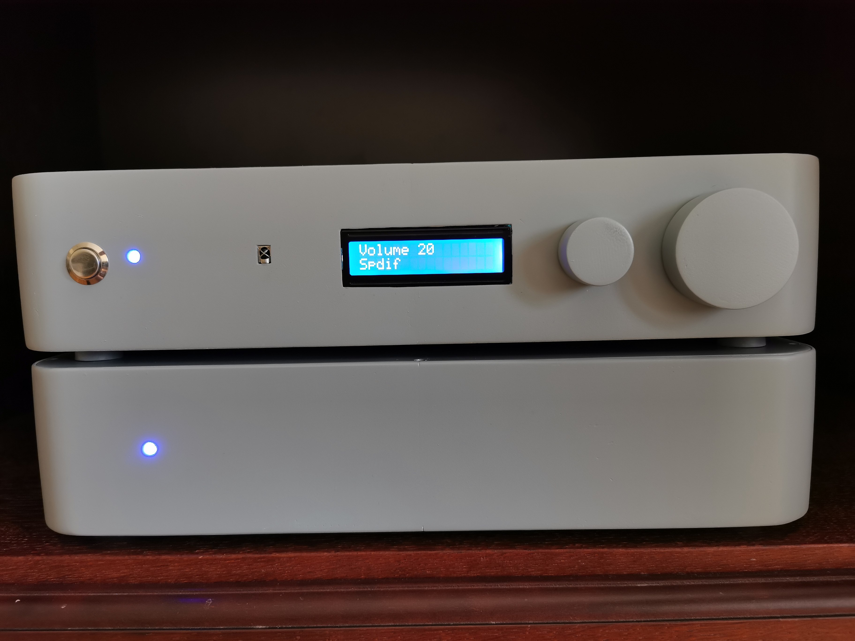
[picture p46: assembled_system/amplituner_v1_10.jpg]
amplituner_10

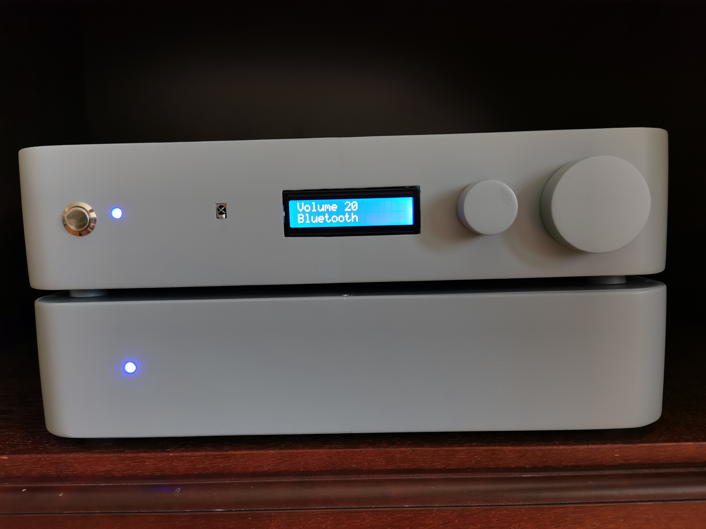
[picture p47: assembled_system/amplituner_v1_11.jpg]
amplituner_11

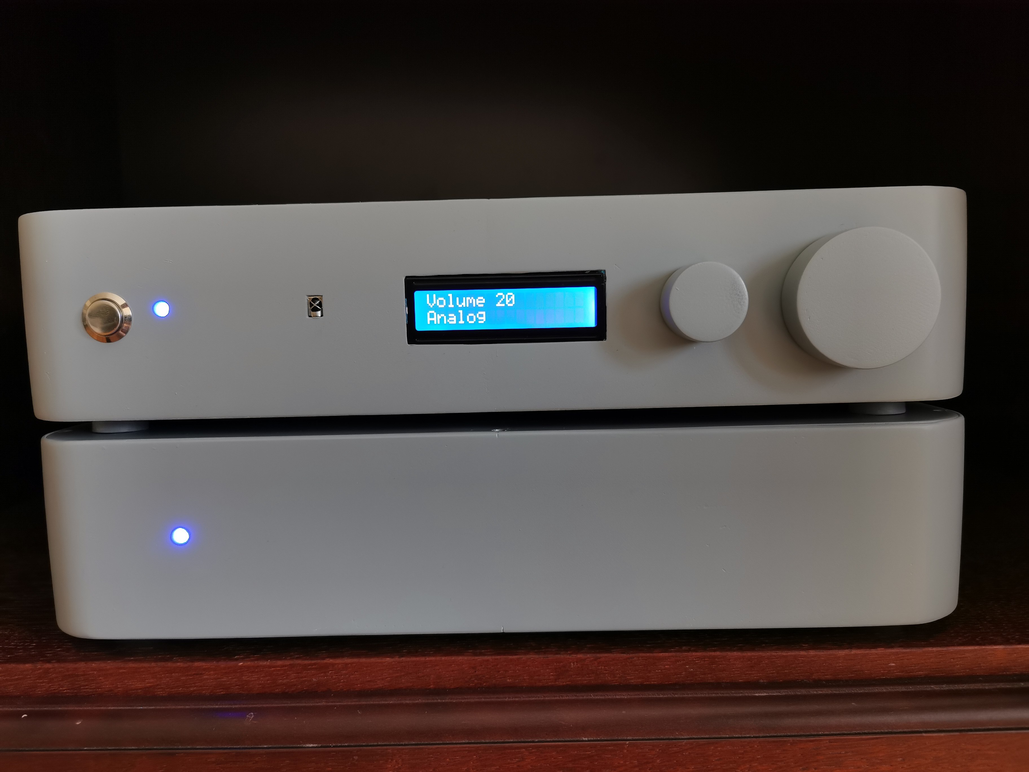
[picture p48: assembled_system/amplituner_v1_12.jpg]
amplituner_12

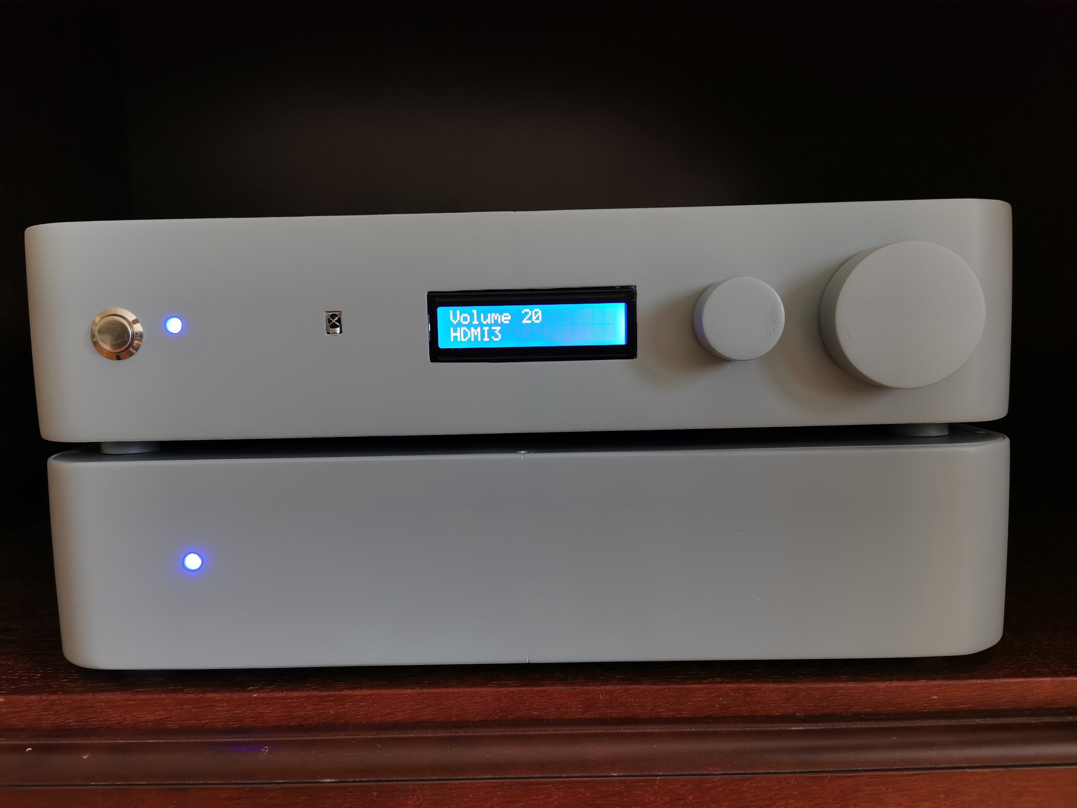
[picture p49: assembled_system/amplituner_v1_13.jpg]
amplituner_13

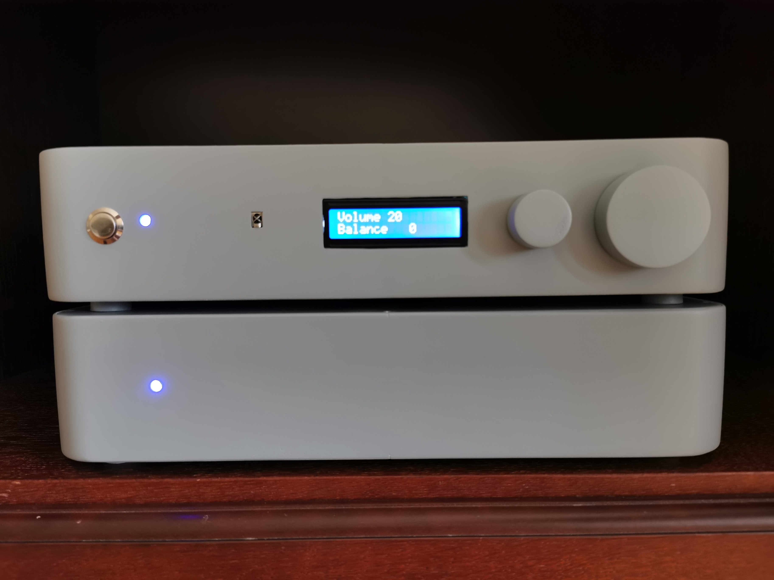
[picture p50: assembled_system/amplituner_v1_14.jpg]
amplituner_14

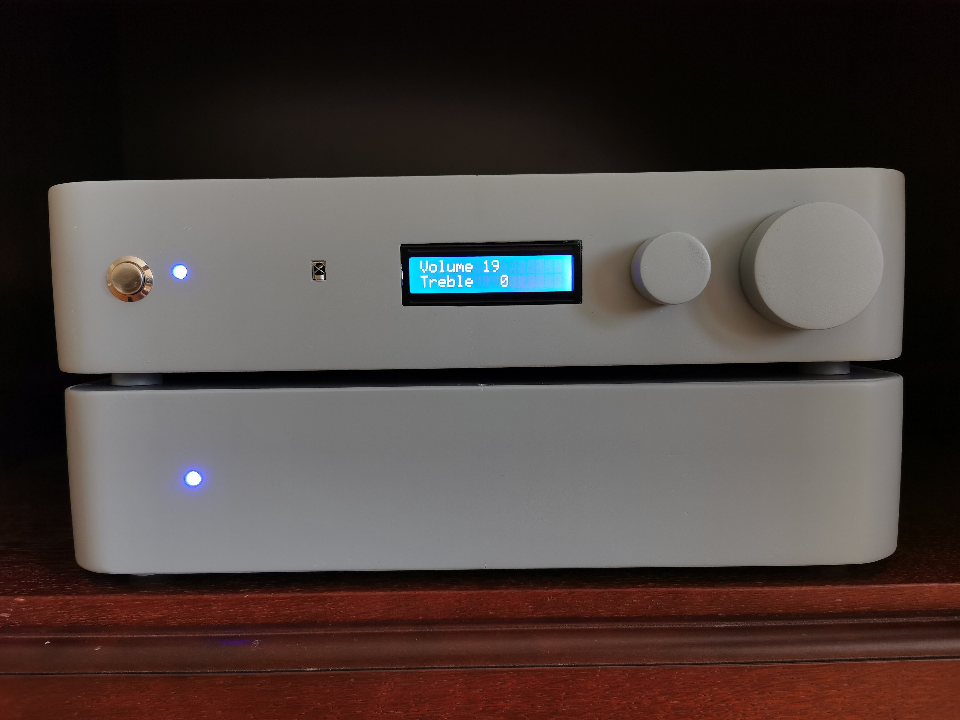
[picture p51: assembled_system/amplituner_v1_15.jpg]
amplituner_15

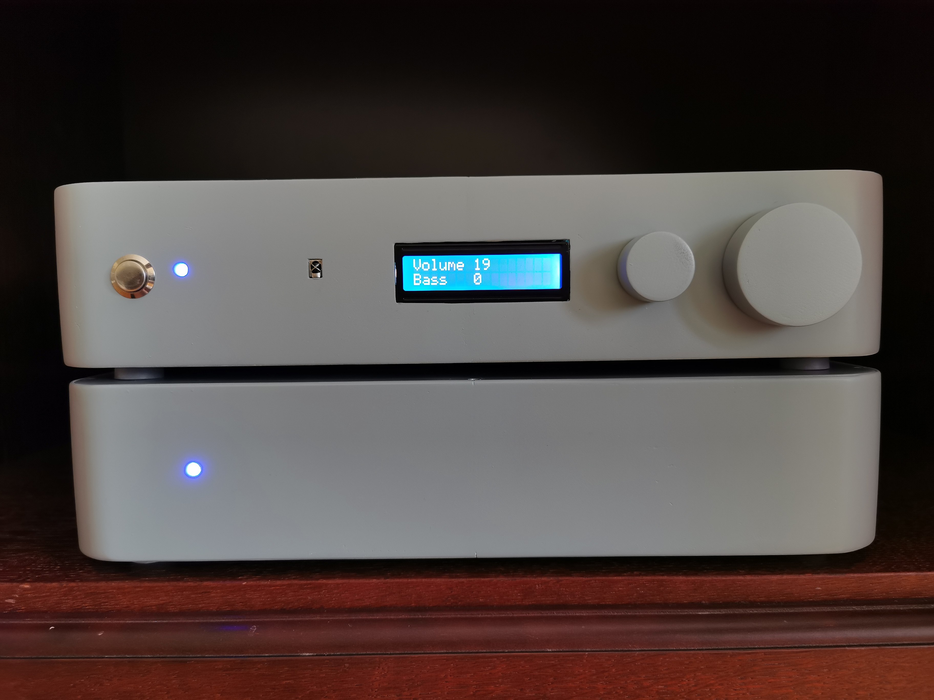
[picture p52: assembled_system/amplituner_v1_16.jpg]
amplituner_15

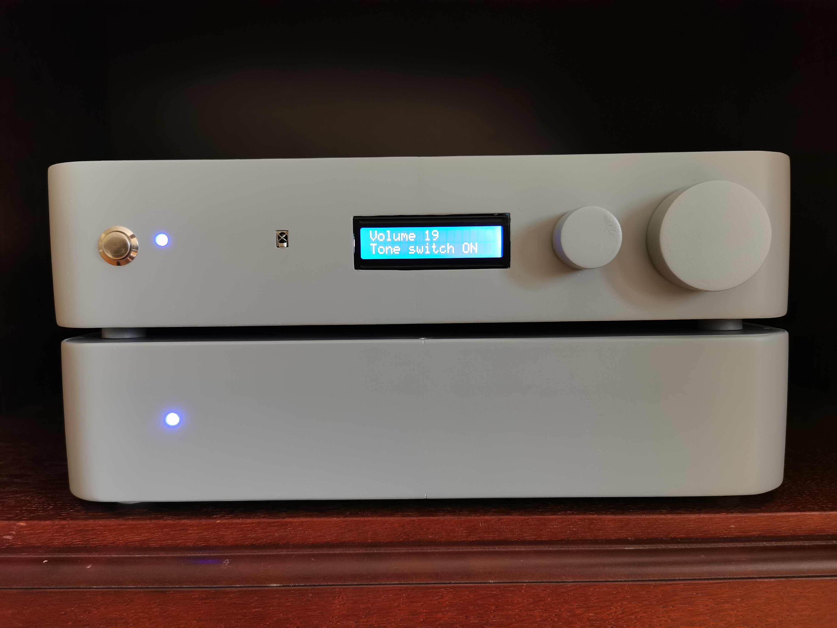
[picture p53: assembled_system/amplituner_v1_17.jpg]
amplituner_15

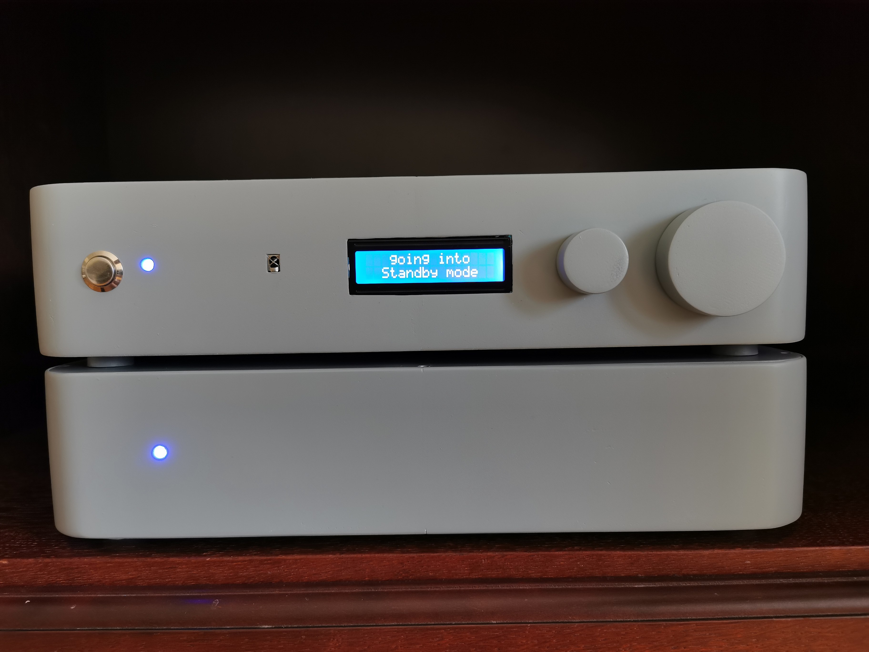
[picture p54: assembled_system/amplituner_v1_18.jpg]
amplituner_15


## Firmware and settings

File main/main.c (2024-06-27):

#include <stdio.h>
#include "freertos/FreeRTOS.h"
#include "freertos/task.h"
#include "freertos/idf_additions.h"
#include "driver/gpio.h"
#include "esp_log.h"
#include "sdkconfig.h"
#include "driver/i2c.h"
#include "amp_parameters.h"
#include "lcd.h"
#include "i2c.h"
#include "mcp23017.h"
#include "source.h"
#include "encoder.h"
#include "njw1194.h"
#include "spi.h"
#include "remote.h"


static SemaphoreHandle_t encoderInterruptSemaphore = NULL;
static SemaphoreHandle_t standbyInterruptSemaphore = NULL;
static TaskHandle_t encoderGetTask = NULL;
static TaskHandle_t encoderSetTask = NULL;
static TaskHandle_t encoderInterruptClearTask = NULL;
static TaskHandle_t remoteGetTask = NULL;
static TaskHandle_t remoteSetTask = NULL;
static QueueHandle_t encoderQueue = NULL;
static QueueHandle_t remoteQueue = NULL;
static bool standbyMode = ON;
static int8_t tunerState[OPTION_NO][VAR_NO] = {
    {0, 0, VOL_MIN, VOL_MAX, OVFL_NO},
    {SEL_MIN, 0, SEL_MIN, SEL_MAX, OVFL_YES},
    {0, 0, SRC_MIN, SRC_MAX, OVFL_YES},
    {0, 0, BAL_MIN, BAL_MAX, OVFL_NO},
    {0, 0, TRE_MIN, TRE_MAX, OVFL_NO},
    {0, 0, BAS_MIN, BAS_MAX, OVFL_NO},
    {0, 0, TON_MIN, TON_MAX, OVFL_NO}};
static char sourceAlias[MAX_SOURCES][MAX_SRC_ALIAS_LENGTH] = {
    {"Analog"}, {"HDMI1"}, {"HDMI2"}, {"HDMI3"}, {"HDMI4"}, {"\0"}, {"Spdif"}, {"Bluetooth"}, {"\0"}};
static char optionAlias[OPTION_NO][MAX_OPT_ALIAS_LENGTH] = {
    {"Volume"}, {"Selected"}, {"Source"}, {"Balance"}, {"Treble"}, {"Bass"}, {"Tone switch"}};

static void Initialize(void);
static void DisplayWelcomeMessage(void);
static void DisplayInterface(void);
static void EncoderIsrHandlerAdd(void);
static void EncoderIsrHandlerRemove(void);
static void GpioInit(void);
static void SetupAudioDefaults(void);
static void EncoderInterruptHandler(void *args);
static void BlinkLed(uint8_t state);
static void EncoderGetLoop();
static void EncoderSetLoop();
static void EncoderInterruptClearLoop();
static void RemoteGetLoop();
static void RemoteSetLoop();
static void SetChange(int8_t lastChange);
static void AudioPowerToggle(void);
static void DigitalPowerToggle(void);
static void AmpAudioControl(uint8_t state);
static void Standby(uint8_t state);
static void SetupEncoderTasks(void);
static void DeleteEncoderTasks(void);
static void SetupRemoteTasks(void);
static void StandbyIsrHandlerAdd(void);
static void IsrInit();
static void AmpPowerControl(uint8_t state);

void app_main(void)
{
  Initialize();
  while (1)
  {
    if (xSemaphoreTake(standbyInterruptSemaphore, STANDBY_SEMAPHORE_BLOCK_TIME) == pdPASS)
    {
      uint8_t counter = 0;
      while (gpio_get_level(STANDBY_BUTTON_GPIO) == 0)
      {
        counter++;
        vTaskDelay(STANDBY_BUTTON_DELAY/STANDBY_BUTTON_COUNTER_MAX/portTICK_PERIOD_MS);
        if (counter >= STANDBY_BUTTON_COUNTER_MAX)
        {
          standbyMode = !standbyMode;
          Standby(standbyMode);
          break;
        }
      }
    }
  }
}

static void IsrInit()
{
  esp_err_t ret = gpio_install_isr_service(ESP_INTR_FLAG_IRAM);
  if (LOGE_MAIN && ret != ESP_OK)
  {
    ESP_LOGE(AMP_TAG, "ISR install error.");
  }
}

static void Initialize(void)
{
  GpioInit();
  AmpAudioControl(ON);
  AudioPowerToggle();
  DigitalPowerToggle();
  IsrInit();
  SpiInit();
  I2CInit();
  StandbyIsrHandlerAdd();
  SetupAudioDefaults();
  SetupRemoteTasks();
  BlinkLed(ON);
  if(LOGI_MAIN){
    ESP_LOGI(AMP_TAG, "Init finished. standby: %d", standbyMode);
  }
  standbyInterruptSemaphore = xSemaphoreCreateBinary();
}

static void SetupEncoderTasks(void)
{
  encoderInterruptSemaphore = xSemaphoreCreateBinary();
  encoderQueue = xQueueCreate(ENC_QUEUE_LENGTH, ENCODER_DATA);
  xTaskCreatePinnedToCore(EncoderGetLoop, "EncoderGetLoop", DEFAULT_STACK_DEPTH, NULL, PRIORITY_6, &encoderGetTask, CORE0);
  xTaskCreatePinnedToCore(EncoderSetLoop, "EncoderSetLoop", DEFAULT_STACK_DEPTH, NULL, PRIORITY_5, &encoderSetTask, CORE1);
  xTaskCreatePinnedToCore(EncoderInterruptClearLoop, "EncoderInterruptClearLoop", DEFAULT_STACK_DEPTH, NULL, PRIORITY_1, &encoderInterruptClearTask, CORE1);
}

static void SetupRemoteTasks(void)
{
  xTaskCreatePinnedToCore(RemoteGetLoop, "RemoteGetLoop", DEFAULT_STACK_DEPTH, NULL, PRIORITY_4, &remoteGetTask, CORE0);
  xTaskCreatePinnedToCore(RemoteSetLoop, "RemoteSetLoop", DEFAULT_STACK_DEPTH, NULL, PRIORITY_3, &remoteSetTask, CORE1);
}

static void DeleteEncoderTasks(void)
{
  encoderInterruptSemaphore = NULL;
  encoderQueue = NULL;
  vTaskDelete(encoderGetTask);
  vTaskDelete(encoderSetTask);
  vTaskDelete(encoderInterruptClearTask);
}

static void IRAM_ATTR EncoderGetLoop()
{
  while (1)
  {
    if (xSemaphoreTake(encoderInterruptSemaphore, PORT_DELAY) == pdPASS)
    {
      uint8_t interruptData[2] = {0};
      McpRead(MCP1_ADDRESS, INTFB, &interruptData[0]);
      McpRead(MCP1_ADDRESS, INTCAPB, &interruptData[1]);
      xQueueSend(encoderQueue, &interruptData, PORT_DELAY);
    }
  }
}

static void IRAM_ATTR EncoderSetLoop()
{
  uint8_t interruptData[2] = {0};
  int8_t lastChange=0;
  while (1)
  {
    if(xQueueReceive(encoderQueue, &interruptData, PORT_DELAY)!=pdFALSE)
    {
      lastChange = CreateSnapshot(tunerState, interruptData);
      SetChange(lastChange);
    }
  }
}

static void IRAM_ATTR EncoderInterruptClearLoop()
{
  size_t count = 0;
  while (1)
  {
    if (!gpio_get_level(INTR_PIN))
    {
      count++;
      if (count == 3)
      {
        uint8_t interruptData[2] = {0};
        McpRead(MCP1_ADDRESS, INTFB, &interruptData[0]);
        McpRead(MCP1_ADDRESS, INTCAPB, &interruptData[1]);
        xQueueSend(encoderQueue, &interruptData, PORT_DELAY);
        count = 0;
      }
      vTaskDelay(10 / portTICK_PERIOD_MS);
      continue;
    }
    else
    {
      count = 0;
    }
    vTaskDelay(100 / portTICK_PERIOD_MS);
  }
}

static void IRAM_ATTR RemoteGetLoop()
{
  remoteQueue = xQueueCreate(RMT_QUEUE_LENGTH, REMOTE_DATA);
  if (LOGI_MAIN)
  {
    ESP_LOGI(AMP_TAG, "Create RMT RX channel.");
  }
  rmt_rx_channel_config_t rxChannelCfg = {0};
  rxChannelCfg.clk_src = RMT_CLK_SRC_DEFAULT;
  rxChannelCfg.resolution_hz = IR_RESOLUTION_HZ;
  rxChannelCfg.mem_block_symbols = 64;
  rxChannelCfg.gpio_num = IR_RX_GPIO_NUM;
  rmt_channel_handle_t rxChannel = NULL;
  ESP_ERROR_CHECK(rmt_new_rx_channel(&rxChannelCfg, &rxChannel));
  
  if (LOGI_MAIN)
  {
    ESP_LOGI(AMP_TAG, "Register RX done callback.");
  }
  QueueHandle_t receiveQueue = xQueueCreate(1, sizeof(rmt_rx_done_event_data_t));
  assert(receiveQueue);


  rmt_rx_event_callbacks_t cbs = {0};
  cbs.on_recv_done = RmtRxDoneCallback;
  ESP_ERROR_CHECK(rmt_rx_register_event_callbacks(rxChannel, &cbs, receiveQueue));

  rmt_receive_config_t receiveConfig = {0};
  receiveConfig.signal_range_min_ns = 1250;
  receiveConfig.signal_range_max_ns = 12000000;
  ESP_ERROR_CHECK(rmt_enable(rxChannel));
  rmt_symbol_word_t rawSymbols[64]={0};
  rmt_rx_done_event_data_t rxData={0};
  ESP_ERROR_CHECK(rmt_receive(rxChannel, rawSymbols, sizeof(rawSymbols),&receiveConfig));
  while (1)
  {
    if (xQueueReceive(receiveQueue, &rxData, pdMS_TO_TICKS(1000)) == pdPASS)
    {
      ParseFrame(rxData.received_symbols, rxData.num_symbols, remoteQueue);
      ESP_ERROR_CHECK(rmt_receive(rxChannel, rawSymbols, sizeof(rawSymbols), &receiveConfig));
    }
  }
}

static void IRAM_ATTR RemoteSetLoop()
{
  uint16_t remoteCode[2] = {0};
  int8_t lastChange=0;
  while (1)
  {
    if(xQueueReceive(remoteQueue, &remoteCode, PORT_DELAY)!=pdFALSE)
    {
      lastChange = RemoteParse(tunerState, remoteCode, standbyMode);
      SetChange(lastChange);
    }
  }
}

static void EncoderInterruptHandler(void *args)
{
  BaseType_t xHigherPriorityTaskWoken = pdFALSE;
  xSemaphoreGiveFromISR(encoderInterruptSemaphore, &xHigherPriorityTaskWoken);
}

static void StandbyInterruptHandler(void *args)
{
  BaseType_t xHigherPriorityTaskWoken = pdFALSE;
  xSemaphoreGiveFromISR(standbyInterruptSemaphore, &xHigherPriorityTaskWoken);
}

static void EncoderIsrHandlerAdd(void)
{
  
  gpio_config_t ioConf={0};
  ioConf.intr_type = GPIO_INTR_NEGEDGE;
  ioConf.pin_bit_mask = (1 << INTR_PIN);
  ioConf.mode = GPIO_MODE_INPUT;
  ioConf.pull_down_en = GPIO_PULLDOWN_DISABLE;
  ioConf.pull_up_en = GPIO_PULLUP_ENABLE;
  gpio_config(&ioConf);
  esp_err_t ret = gpio_isr_handler_add(INTR_PIN, EncoderInterruptHandler, NULL);
  if (LOGE_MAIN && ret != ESP_OK)
  {
    ESP_LOGE(AMP_TAG, "Encoder handler add error.");
  }
  else if (LOGI_MAIN)
  {
    ESP_LOGI(AMP_TAG, "Encoder handler add OK.");
  }
}

static void EncoderIsrHandlerRemove(void)
{
  esp_err_t ret = gpio_isr_handler_remove(INTR_PIN);
  if (LOGE_MAIN && ret != ESP_OK)
  {
    ESP_LOGE(AMP_TAG, "Encoder handler remove error.");
  }
  else if (LOGI_MAIN) 
  {
    ESP_LOGI(AMP_TAG, "Encoder handler remove OK.");
  }
}

static void StandbyIsrHandlerAdd(void)
{
  gpio_config_t ioConf={0};
  ioConf.intr_type = GPIO_INTR_NEGEDGE;
  ioConf.pin_bit_mask = (1ULL << STANDBY_BUTTON_GPIO);
  ioConf.mode = GPIO_MODE_INPUT;
  ioConf.pull_down_en = GPIO_PULLDOWN_DISABLE;
  ioConf.pull_up_en = GPIO_PULLUP_ENABLE;
  gpio_config(&ioConf);
  esp_err_t ret = gpio_isr_handler_add(STANDBY_BUTTON_GPIO, StandbyInterruptHandler, NULL);
  if (LOGE_MAIN && ret != ESP_OK)
  {
    ESP_LOGE(AMP_TAG, "Standby handler add error.");
  }
  else if (LOGI_MAIN)
  {
    ESP_LOGI(AMP_TAG, "Standby handler add OK.");
  }
}

static void DisplayWelcomeMessage(void)
{
  LcdText(0, 2, "   Tuner");
  LcdText(1, 1, "version 1.0");
}

static void DisplayInterface(void)
{
  LcdClear();
  SetChange(SOURCE);
  LcdText(0, 0, optionAlias[VOLUME]);
  SetChange(VOLUME);
}

static void SetupAudioDefaults(void)
{
  tunerState[VOLUME][ACT_VAL] = VOL_DEFAULT;
  tunerState[VOLUME][LAS_VAL] = VOL_DEFAULT;
  tunerState[SOURCE][ACT_VAL] = SRC_DEFAULT;
  tunerState[SOURCE][LAS_VAL] = SRC_DEFAULT;
  tunerState[BALANCE][ACT_VAL] = BAL_DEFAULT;
  tunerState[TREBLE][ACT_VAL] = TRE_DEFAULT;
  tunerState[BASS][ACT_VAL] = BAS_DEFAULT;
  tunerState[TONE_SW][ACT_VAL] = TON_DEFAULT;
}

static void BlinkLed(uint8_t state)
{
  gpio_set_level(LED_GPIO, state);
}

static void GpioInit(void)
{
  gpio_set_direction(LED_GPIO, GPIO_MODE_OUTPUT);
  gpio_set_direction(AMP_POWER_CONTROL_GPIO, GPIO_MODE_OUTPUT);
  gpio_set_direction(AMP_AUDIO_CONTROL_GPIO, GPIO_MODE_OUTPUT);
  gpio_set_direction(AUDIO_POWER_CONTROL_GPIO, GPIO_MODE_OUTPUT);
  gpio_set_direction(DIGITAL_POWER_CONTROL_GPIO, GPIO_MODE_OUTPUT);
}

static void AudioPowerToggle(void)
{
  // bistable module
  vTaskDelay(60 / portTICK_PERIOD_MS);
  gpio_set_level(AUDIO_POWER_CONTROL_GPIO, ON);
  vTaskDelay(60 / portTICK_PERIOD_MS);
  gpio_set_level(AUDIO_POWER_CONTROL_GPIO, OFF);
}

static void DigitalPowerToggle(void)
{
  // bistable module
  vTaskDelay(60 / portTICK_PERIOD_MS);
  gpio_set_level(DIGITAL_POWER_CONTROL_GPIO, ON);
  vTaskDelay(60 / portTICK_PERIOD_MS);
  gpio_set_level(DIGITAL_POWER_CONTROL_GPIO, OFF);
}

static void AmpAudioControl(uint8_t state)
{
  gpio_set_level(AMP_AUDIO_CONTROL_GPIO, state);
}

static void AmpPowerControl(uint8_t state)
{
  gpio_set_level(AMP_POWER_CONTROL_GPIO, state);
}

static void IRAM_ATTR SetChange(int8_t lastChange)
{
  char buffer[17];
  switch (lastChange)
  {
  case SOURCE:
    SetVolume(tunerState[VOLUME][MIN_VAL], tunerState[BALANCE][ACT_VAL]);
    SetSource(tunerState);
    sprintf(buffer, "%s", sourceAlias[tunerState[SOURCE][ACT_VAL]]);
    LcdClearLine(1);
    LcdText(1, 0, buffer);
    SetVolume(tunerState[VOLUME][ACT_VAL], tunerState[BALANCE][ACT_VAL]);
    break;
  case VOLUME:
    SetVolume(tunerState[VOLUME][ACT_VAL], tunerState[BALANCE][ACT_VAL]);
    sprintf(buffer, "%2d", tunerState[VOLUME][ACT_VAL]);
    LcdText(0, 7, buffer);
    break;
  case STANDBY:
    standbyMode = !standbyMode;
    Standby(standbyMode);
    break;
  case BALANCE:
    SetVolume(tunerState[VOLUME][ACT_VAL], tunerState[BALANCE][ACT_VAL]);
    sprintf(buffer, "%3d", tunerState[BALANCE][ACT_VAL]);
    LcdText(1, 8, buffer);
    break;
  case TREBLE:
    SetTone(tunerState[TONE_SW][ACT_VAL], TREBLE_CTRL, tunerState[TREBLE][ACT_VAL]);
    sprintf(buffer, "%3d", tunerState[TREBLE][ACT_VAL]);
    LcdText(1, 7, buffer);
    break;
  case BASS:
    SetTone(tunerState[TONE_SW][ACT_VAL], BASS_CTRL, tunerState[BASS][ACT_VAL]);
    sprintf(buffer, "%3d", tunerState[BASS][ACT_VAL]);
    LcdText(1, 5, buffer);
    break;
  case TONE_SW:
    SetTone(tunerState[TONE_SW][ACT_VAL], TREBLE_CTRL, tunerState[TREBLE][ACT_VAL]);
    if (tunerState[TONE_SW][ACT_VAL] == 1)
      sprintf(buffer, "%s", "ON ");
    else
      sprintf(buffer, "%s", "OFF");
    LcdText(1, 12, buffer);
    break;
  case SELECTED:
    LcdClearLine(1);
    if (tunerState[SELECTED][ACT_VAL] == SOURCE)
    {
      sprintf(buffer, "%s", sourceAlias[tunerState[SOURCE][ACT_VAL]]);
    }
    else if (tunerState[SELECTED][ACT_VAL] == TONE_SW && tunerState[TONE_SW][ACT_VAL] == 1)
    {
      sprintf(buffer, "%s %s", optionAlias[tunerState[SELECTED][ACT_VAL]], "ON");
    }
    else if (tunerState[SELECTED][ACT_VAL] == TONE_SW && tunerState[TONE_SW][ACT_VAL] == 0)
    {
      sprintf(buffer, "%s %s", optionAlias[tunerState[SELECTED][ACT_VAL]], "OFF");
    }
    else
    {
      sprintf(buffer, "%s %3d", optionAlias[tunerState[SELECTED][ACT_VAL]], tunerState[tunerState[SELECTED][ACT_VAL]][ACT_VAL]);
    }
    LcdText(1, 0, buffer);
  }
}

static void Standby(uint8_t state)
{
  if (state == ON)
  {
    if (LOGI_MAIN)
    {
      ESP_LOGI(AMP_TAG, "Going into standby mode.");
    }
    AmpAudioControl(ON);
    AudioPowerToggle();
    AmpPowerControl(ON);
    LcdClear();
    LcdText(0, 0, "   going into");
    LcdText(1, 0, "  Standby mode");
    SetVolume(tunerState[VOLUME][MIN_VAL], tunerState[BALANCE][ACT_VAL]);
    SetAnalogInput(INPUT_MUTE);
    EncoderIsrHandlerRemove();
    SpiBusRemoveNjw1194();
    DeleteEncoderTasks();
    vTaskDelay(1000 / portTICK_PERIOD_MS);
    DigitalPowerToggle();
    if (LOGI_MAIN)
    {
      ESP_LOGI(AMP_TAG, "Stanby mode ON");
    }
    LcdClear();
  }
  else if (state == OFF)
  {
    if (LOGI_MAIN)
    {
      ESP_LOGI(AMP_TAG, "Waking up from Stanby mode");
    }
    AmpAudioControl(ON);
    AmpPowerControl(OFF);
    DigitalPowerToggle();
    AudioPowerToggle();
    vTaskDelay(200 / portTICK_PERIOD_MS);
    McpInit(MCP1_ADDRESS);
    LcdInit();
    DisplayWelcomeMessage();
    SetupEncoderTasks();
    EncoderIsrHandlerAdd();
    SpiBusAddNjw1194();
    SourcesInit();
    SetTone(tunerState[TONE_SW][ACT_VAL], TREBLE_CTRL, tunerState[TREBLE][ACT_VAL]);
    SetTone(tunerState[TONE_SW][ACT_VAL], BASS_CTRL, tunerState[BASS][ACT_VAL]);
    SetSource(tunerState);
    if (tunerState[VOLUME][ACT_VAL]>VOL_MAX_ON_STARTUP){
      tunerState[VOLUME][ACT_VAL] = VOL_MAX_ON_STARTUP;
    }
    SetVolume(tunerState[VOLUME][ACT_VAL], tunerState[BALANCE][ACT_VAL]);
    DisplayInterface();
    AmpAudioControl(OFF);
    if (LOGI_MAIN)
    {
      ESP_LOGI(AMP_TAG, "Stanby mode off");
    }
  }
}

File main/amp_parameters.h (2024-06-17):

#define OPTION_NO (uint8_t)7
#define VAR_NO (uint8_t)5
#define MAX_SRC_ALIAS_LENGTH (uint8_t)16
#define MAX_OPT_ALIAS_LENGTH (uint8_t)12
#define MAX_SOURCES (uint8_t)9


#ifndef _amp_parameters_H_
#define _amp_parameters_H_

static const uint8_t LOGE_MAIN = false;
static const uint8_t LOGI_MAIN = false;

static char* const AMP_TAG = "AmpliTuner";
static const gpio_num_t LED_GPIO = GPIO_NUM_2;
static const gpio_num_t STANDBY_BUTTON_GPIO = GPIO_NUM_27;
static const gpio_num_t AUDIO_POWER_CONTROL_GPIO = GPIO_NUM_18;
static const gpio_num_t DIGITAL_POWER_CONTROL_GPIO = GPIO_NUM_26;
static const gpio_num_t AMP_AUDIO_CONTROL_GPIO = GPIO_NUM_25;
static const gpio_num_t AMP_POWER_CONTROL_GPIO = GPIO_NUM_33;
static const uint32_t STANDBY_SEMAPHORE_BLOCK_TIME = 1500;
static const uint32_t STANDBY_BUTTON_DELAY = 500;
static const uint8_t STANDBY_BUTTON_COUNTER_MAX = 5;
static const uint32_t DEFAULT_STACK_DEPTH = 4096;
static const BaseType_t CORE0 = 0;
static const BaseType_t CORE1 = 1;
static const UBaseType_t PRIORITY_1 = 1;
static const UBaseType_t PRIORITY_2 = 2;
static const UBaseType_t PRIORITY_3 = 3;
static const UBaseType_t PRIORITY_4 = 4;
static const UBaseType_t PRIORITY_5 = 5;
static const UBaseType_t PRIORITY_6 = 6;

static const int8_t VOL_MIN = 0;
static const int8_t VOL_MAX = 40;
static const int8_t VOL_DEFAULT = 17;
static const int8_t VOL_MAX_ON_STARTUP = 22;
static const int8_t SRC_MAX = 7;
static const int8_t SRC_MIN = 0;
static const int8_t SRC_DEFAULT = 5; //Spdif
static const int8_t BAL_MAX = 20;
static const int8_t BAL_MIN = -20;
static const int8_t BAL_DEFAULT = 0;
static const int8_t TRE_MAX = 10;
static const int8_t TRE_MIN = -10;
static const int8_t TRE_DEFAULT = 0;
static const int8_t BAS_MAX = 10;
static const int8_t BAS_MIN = -10;
static const int8_t BAS_DEFAULT = 0;
static const int8_t TON_MAX = 1;
static const int8_t TON_MIN = 0;
static const int8_t TON_DEFAULT = 0;
static const int8_t SEL_MIN = 2;
static const int8_t SEL_MAX = 6;

static const int8_t NONE = -1;
static const int8_t VOLUME = 0;
static const int8_t SELECTED = 1;
static const int8_t SOURCE = 2;
static const int8_t BALANCE = 3;
static const int8_t TREBLE = 4;
static const int8_t BASS = 5;
static const int8_t TONE_SW = 6;
static const int8_t STANDBY = 7;

static const int8_t VAR_MIN = 0;
static const int8_t VAR_MAX = 3;
static const int8_t ACT_VAL = 0;
static const int8_t LAS_VAL = 1;
static const int8_t MIN_VAL = 2;
static const int8_t MAX_VAL = 3;
static const int8_t OVFL_VAL = 4;
static const int8_t OVFL_NO = 0;
static const int8_t OVFL_YES = 1;
static const int8_t PORT_DELAY = 2;
static const int8_t ENC_QUEUE_LENGTH = 40;
static const int8_t RMT_QUEUE_LENGTH = 20;
static const int8_t ON = 1;
static const int8_t OFF = 0;

#endif

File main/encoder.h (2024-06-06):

#include <stdint.h>
#include <stdlib.h>
#include <stdio.h>
#include <string.h>
#include <esp_err.h>
#include "esp_log.h"
#include "i2c.h"
#include "mcp23017.h"
#include "freertos/FreeRTOS.h"
#include "freertos/task.h"
#include "driver/gpio.h"
#include "amp_parameters.h"

#ifndef _encoder_parameters_H_
#define _encoder_parameters_H_
static const uint8_t LOGE_ENC = false;
static const uint8_t LOGI_ENC = false;
static char* const ENC_TAG = "Encoder";

/* MCP1, GPIOB values (8 bits), PIN 2-7 */
static const uint8_t ENCODER_DATA = 2;
static const int8_t SNAP_SIZE = 4;
static const uint8_t ENC1_PINA = 2;
static const uint8_t ENC1_PINB = 3;
static const uint8_t ENC1_SW_PIN = 4;
static const uint8_t ENC2_PINA = 5;
static const uint8_t ENC2_PINB = 6;
static const uint8_t ENC2_SW_PIN = 7;

static const int8_t PINA = 0;
static const int8_t PINB = 1;
static const int8_t PINA_VAL = 2;
static const int8_t PINB_VAL = 3;

static const uint8_t MAIN_BUT_PIN = 0x14;
static const gpio_num_t INTR_PIN = GPIO_NUM_4;
static const uint8_t INTR_DEFAULT_FLAG = 0;
static const uint8_t TRUE = 1;
static const uint8_t FALSE = 0;

static const uint8_t ENC1_TOG = 0;
static const uint8_t ENC1_SW = 1;
static const uint8_t ENC2_TOG = 2;
static const uint8_t ENC2_SW = 3;

int8_t CreateSnapshot(int8_t (*tunerState)[VAR_NO], uint8_t *interruptData);
int8_t CheckInterrupt(int8_t (*tunerState)[VAR_NO]);
int8_t CheckOverflow(int8_t (*tunerState)[VAR_NO], int8_t select);
int8_t DecodePins(uint8_t *snapshot, int8_t (*tunerState)[VAR_NO]);
int8_t OptionControl(uint8_t *snapshot, int8_t (*tunerState)[VAR_NO], int8_t option);
int8_t ButtonControl(int8_t (*tunerState)[VAR_NO], int8_t option);
int8_t Mute(int8_t (*tunerState)[VAR_NO], int8_t option);
int8_t Toggle(int8_t (*tunerState)[VAR_NO], int8_t option);
#endif

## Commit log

2024-06-06 refactoring, removved get encoder and get remote loops error
    [amp_parameters.h, encoder.h, i2c.c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]
2024-06-07 LCD Init - init timing issues resolved
    [lcd.c, main.c]
2024-06-17 knobs and refactor
    [option_knob.stl, volume_knob.stl]
2024-06-18 enclosure error
2024-06-20 amp power
